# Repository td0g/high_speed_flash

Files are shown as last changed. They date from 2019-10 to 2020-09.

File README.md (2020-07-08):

# high_speed_flash
This is the data repository for my microsecond strobe designs.  They are high-speed flashes used for photographing bullets or other projectiles or processes.  The entire project is open-source.

## MK1 - The Edgerton

The original strobe was designed to be simple to assemble and as affordable as possible.  Photographers, please be aware that some soldering skills are required.

## MK2 - The E2 Series

These are called a series because multiple submodels are planned.  Currently only the E2-A is complete.

The E2 series are very similar to the MK1 Edgerton, but have been designed with commercial production in mind.  You can build one yourself, but some more complicated processes are involved.  Additionally, the total cost is slightly higher.  The advantage is that the E2 series is smaller, more robust, and easier to use.

### Planned E2 Submodels:

E2-A | E2-K | E2-V
------------ | ------------- | -------------
Standard | High-powered 1-microsecond | Videographer
**Plans & specs available** | In development | In development
Strobe only | Strobe only | **120+ Watt Constant illumination mode**
Battery only | Battery only | **Battery OR external power supply**
**0.5 - 4 microsecond strobe** | 0.5 - 1 microsecond strobe | **0.5 - 4 microsecond strobe**
Standard LED Power | **Increased LED Power** | Standard LED Power
**Well-Established Safety Margin** | LED's more likely to fail | **Well-Established Safety Margin**

## Comparison

If you are trying to decide which design to use, have a look through this comparison.  Only the E2-A submodel is compared as it is most similar to the original Edgerton.

MK1 Edgerton | MK2 E2-A
------------ | -------------
**Same Performance** | **Same Performance**
**Affordable** | About 30% more expensive
**Relatively simple to assemble** (3D printer, soldering skills, Through-Hole Components) | Slightly more difficult (Aluminum milling / drilling, better cable management required, Surface-Mount Components)
Reliable | **Reliable PLUS**
8x AA batteries | **4x AA batteries**
Battery compartment difficult to access | **Easy to use battery compartment**
Cheap display | **Attractive, intuitive display**
Larger | **Smaller**
Single strobes only | **Multi-strobe capable**

## Research & Testing
The most valuable part of this project is the research and testing.  Many LED's have been destructively tested to find their limitations.  I plan to upload all of my testing data to this repository and encourage others to share any testing performed as well.

## License

Documentation is licensed under a [Creative Commons Attribution 4.0 International License](https://creativecommons.org/licenses/by/4.0/)

Software is licensed under a [GNU GPL v3 License](https://www.gnu.org/licenses/gpl-3.0.txt)

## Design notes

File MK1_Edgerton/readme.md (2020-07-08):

# The Original Design!

Edgerton is a high-speed flash used for photographing bullets or other projectiles.  The project is open-source.  Please see https://hackaday.io/project/165622-edgerton-a-high-speed-led-flash for more information.

## Building Your Flash
Please download and follow the [Assembly Manual](https://github.com/td0g/high_speed_flash/blob/master/MK1_Edgerton/Assembly%20Manual%201.3.pdf).  This detailed manual should answer most of your questions.

The main control board can be built in several ways.  You may build it using a blank perfboard PCB (See the perfboard layout), by etching and drilling your own PCB (See the Gerber files), or by purchasing a control board from me (https://www.tindie.com/products/19592/).

The firmware has been tested and will make setup quick and easy.  Please flash it to your microcontroller using the Arduino IDE.  Before turning on your flash, please review the User's Manual.

## Files

**Assembly Manual** - The best way to build the flash

**GERBER's** - All the files you need to send to a board house if you want to have the control board built

**Firmware** - In the **edgerton** folder.  Upload using the Arduino IDE.

## License

Documentation is licensed under a [Creative Commons Attribution 4.0 International License](https://creativecommons.org/licenses/by/4.0/)

Software is licensed under a [GNU GPL v3 License](https://www.gnu.org/licenses/gpl-3.0.txt)

## ToDo

Finish this readme

EMCB0 Control Board: R6 text is under SSR, cannot see it... 220uF cap is in bad spot

Firmware: Add interrupt blocking

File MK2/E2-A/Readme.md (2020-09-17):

# The MK2!

Building on the original Edgerton design, the E2-A is a high-speed flash used for photographing bullets or other projectiles.  The project is open-source.  Please see https://td0g.ca/2020/06/29/e2-a-the-high-speed-led-strobe-mk-2/ for more information.

## Building Your Flash
Please download and follow the [Assembly Manual](https://github.com/td0g/high_speed_flash/raw/master/MK2/E2-A/E2-A%20Assembly%20Manual.pdf).  This detailed manual should answer most of your questions.  Please contact me at tyler@td0g.ca if you find any errors or inconsistencies, or simply have questions!

The **EMCB1** main control board is slightly different than the one on the original Edgerton.  I plan to manufacture a few and make them available for sale.  You can also manufacture your own using the documentation in this repository!

The **ECC0** high-voltage boost converter is my own design.  Just like the EMCB1, you may build your own or contact me to purchase one.  Note that the ECC0 may eventually be updated to be compatible with the Edgerton design, but for now the maximum input voltage is 6 Volts.

The firmware has been tested and will make setup quick and easy.  Please flash it to your microcontroller using the Arduino IDE.  Before turning on your flash, please review the User's Manual.

## Files

**Assembly Manual** - The best way to build the flash

**GERBER's** - All the files you need to send to a board house if you want to have the control board built

**BOM** - Itemized list of all materials needed to manufacture the E2-A

**Firmware** - Upload using the Arduino IDE

**STL** - 3D print files

**Mechanical Drawings** - Drawings for manufacturing the aluminum faceplate

## License

Documentation is licensed under a [Creative Commons Attribution 4.0 International License](https://creativecommons.org/licenses/by/4.0/)

Software is licensed under a [GNU GPL v3 License](https://www.gnu.org/licenses/gpl-3.0.txt)

## Roadmap

### Rev 0

COMPLETE

### Rev 1

Finish this readme

Assembly Manual - complete and upload

Back_Cover.STL - redesign external trigger jack housing

EMCB1 - Some components are placed too closely, will need to increase board width by a couple mm

Operator's Manual - update

### Rev 2

Adding third PCB to design: EIB0.  This board will be mounted near the encoder and display.  It will host the 5V and 12.8V regulator.  The 12.8V regulator will be an SX1308-based boost converter, no longer an off-the-shelf converter.  The board will be connected to the EMCB1 control board using an FFC ribbon, which will dramatically improve cable management.  Battery power will be supplied to the EMCB1 by 22-gauge wires so that the XL6005 and MIC3172 have ample current supply.

The EMCB1 board will be updated with a 'modelling lamp' function, based on the XL6005 boost converter SMPS.  Max power is ~10W, efficiency is ~60%.

The EMCB1 and ECC0 boards will be modified such that they can connect directly - no wires.  Fewer wires = fewer failure opportunities and more compact design

The film capacitors will be rotated slightly to improve spacing.

USB-C connector on case to power strobe (eg. Raspberry Pi 4 PSU).  Adding CH340 chip so that FTDI adapter isn't required for firmware updates - just use USB-C connection.  See https://github.com/sparkfun/Serial_Basic_Breakout-CH340C

INVESTIGATE: Modified version to use 18650 battery(s).  1x 18650 would run the strobe, 2x could run the XL6005 boost converter at a higher power than 4x AA batteries.

INVESTIGATE: Increasing maximum exposure time

INVESTIGATE: Replacing TC4452 gate driver with more powerful driver

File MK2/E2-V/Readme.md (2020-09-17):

# The Video Version!

An extension of the E2-A, the E2-V has all of the same functionality but includes a constant-illumination mode.  The project is open-source.  Please see https://td0g.ca/2020/06/29/e2-a-the-high-speed-led-strobe-mk-2/ for more information.

## What's The Same / Different?

Much of the design should remain the same.  The goal is to have an external power supply which can be connected in place of the battery to provide constant current to the LED's.

The gate driver needs to have an automated switch for the high-pass filter which disables the filter if the LED capacitor anode voltage is less than ~45 volts.  Otherwise the external power supply cannot provide constant current to the LED's as the transistors cannot remain on for more than 4.5 microseconds.

An offline drive would seem to be the simplest approach, but designing the driver safely presents a significant challenge.  A safer alternative would be to use a 140-watt encapsulated 36V or 48V power supply to power a buck converter.

Because the external power supply will operate with its ground common to the strobe, it requires a high-side switching buck power supply.  The LM3409HV seems to be a suitable candidate.

The buck power supply must be controlled by the strobe.  An opto-isolated interface bus would seem to be the safest way.

The external power supply must also supply a ~6-volt rail to power the strobe.  This requires yet another buck power supply.

Finally, the firmware must be heavily modified to control the power supplies safely.

## ToDo

Finish development of the LM3409HV-based LED driver

Develop 48V to 6V buck regulator

Modify firmware to support constant illumination mode

Integrate LED driver into E2 design

Ensure LED's are load balanced (https://www.onsemi.com/pub/Collateral/AND8109-D.PDF)

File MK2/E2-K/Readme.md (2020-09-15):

# The MK2 - With Extra Power!

An extension of the E2-A, the E2-K is designed for higher power and shorter strobe durations.  The project is open-source.  Please see https://td0g.ca/2020/06/29/e2-a-the-high-speed-led-strobe-mk-2/ for more information.

## What's The Same / Different?

The CREE CXA2530 remains the best bang-for-buck LED in its class.  So there's no point in using a different LED.

Adding more LED's is a possibility, but doing so would require a new mechanical design and gate driver circuit.  It's more economical to use two strobes instead of redesigning.  So the E2-K will continue to use 12x LED's.

The 120V limitation in the E2-A is well within the safe limits of the LED, given a maximum strobe duration of 4 microseconds.  It can even do it three times in a row at 1 kHz!  So, it seems possible that the LED voltage can be increased significantly - perhaps greater than 200V.  This would result in more power output.  To protect the LED's, the maximum strobe duration would be limited to 1 microsecond.  The maximum strobe rate would be set to 1 Hz - no multi-strobe bursts!

## ToDo

Develop firmware with modified limitations (1 microsecond MAX, no multi-strobes)

Source a transistor: Ids >60A, Vds >250V

Test (and possibly modify) gate driver circuit

Conduct testing to find safe limitations for E2-K

Identify causes of failure, work to prevent them

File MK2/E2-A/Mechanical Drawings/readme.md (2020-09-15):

## Files:

### Face Plate

Required for E2-A.  

Recommended material: Aluminium (Anodized if possible).  Currently looking into possibility of 3D printing this component for those who do not have access to mill.

Note: Contours in recessed slots is not strictly required, but highly recommended to prevent contact by the conductors.

### L-Bracket

Optional equipment for E2-A.  Allows mounting on 3 sides of strobe.

Recommended material: Aluminum or Steel

Note:  Contours are primarily asthetic and are not required.

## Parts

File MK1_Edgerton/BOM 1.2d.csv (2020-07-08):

Notes
 |  | Digikey is my preferred vendor (Good prices, cheapest shipping, ships from Winnipeg) but Mouser and others are good as well. Same with eBay/Alibaba/Bangood.
 |  | Most components from eBay could be purchased from Digikey, just an increase in cost (but faster shipping!)
 |  | DO NOT purchase LED’s from eBay/Alibaba. Testing has shown that LED’s from untrustworthy vendors are a lower quality.
Part# | Board Ref | Manufacturer Model | Description | Qty | Suggested Vendor | Vendor Part # | Link
1 |  | CREE CXA2530-0000-U20E3 | LED | 12 | Digikey | CXA2530-0000-000N00U20E3-ND | https://www.digikey.ca/product-detail/en/cree-inc/CXA2530-0000-000N00U20E3/CXA2530-0000-000N00U20E3-ND/3647354
2 |  | Vishay MKP1848S | 10uf Film Capacitor | 4 | Digikey | BC2783-ND | https://www.digikey.ca/product-detail/en/vishay-bc-components/MKP1848S61070JP2C/BC2783-ND/3053104
3 |  | INFINEON IPP60R190P6 | N-Channel MOSFET | 4 | Digikey | IPP60R190P6XKSA1-ND | https://www.digikey.ca/product-detail/en/infineon-technologies/IPP60R190P6XKSA1/IPP60R190P6XKSA1-ND/4248888
4 |  | 45-390V Boost Regulator | Boost Regulator | 1 | eBay |  | https://www.ebay.ca/itm/DC-DC-10-32V-to-45-390V-High-Voltage-Boost-Converter-Step-up-Booster-Module-BB/192918513095
5 |  | 5x7cm PCB Perf Board, Single-Side Tinned OR EMCB0 | PCB | 1 | eBay |  | https://www.ebay.ca/itm/10pcs-DIY-Prototype-Paper-PCB-Universal-Board-5-7-cm-5-7-cm/201414877045
6 | U3 | ATMEL ATMega328P | Microcontroller | 1 | Digikey | ATMEGA328-PU-ND | https://www.digikey.ca/product-detail/en/microchip-technology/ATMEGA328-PU/ATMEGA328-PU-ND/2271026
7 | U1 | LM7805 | Linear Regulator | 1 | eBay
8 | U4 | Microchip TC4452 | Gate Driver | 1 | Digikey | TC4452VPA-ND | https://www.digikey.ca/product-detail/en/microchip-technology/TC4452VPA/TC4452VPA-ND/1098934
9 | U2 | Vishay VO14642AT (Or similar... eBay buyers can probably use AQV252G drop-in replacement) | Solid State Relay | 1 | Digikey | VO14642AT-ND | https://www.digikey.ca/product-detail/en/vishay-semiconductor-opto-division/VO14642AT/VO14642AT-ND/4074374
10 | D1, D2 | 1N5817 | Schottky Diode | 2 | eBay |  | https://www.ebay.ca/itm/Rectifier-Diodes-10A10-1N4001-1N4007-1N5402-1N5408-1N5399-1N914-1N-series-BBC/142919748646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
11 | D3 | 1N5380 | 120V Zener Diode | 1 | Digikey
12 | C6 |  | 2.2nF 10V Ceramic Cap | 1 | eBay
13 | C1, C4, C5 | RDER71E104K0P1H03B | 100nF 10V Ceramic Capacitor, 10% | 3 | Digikey | 490-8809-ND | https://www.digikey.ca/product-detail/en/murata-electronics-north-america/RDER71E104K0P1H03B/490-8809-ND/4770964
14 | C7, C8 | FG11X7S1H106KRT06 | 10uF 25V Ceramic Capacitor | 2 | Digikey | 445-180817-1-ND | https://www.digikey.ca/product-detail/en/tdk-corporation/FG11X7S1H106KRT06/445-180817-1-ND/9560943
15 | C2 | 2.2uF 10V Ceramic Cap | Capacitor | 1 | eBay
16 | C3 | 220uF 10V Electrolytic Cap | Capacitor | 1 | eBay
17 | R1 | 47K Res | Resistor | 1 | eBay
18 | R2 | 33K Res | Resistor | 1 | eBay
19 | R3 | 10K Res | Resistor | 1 | eBay
20 | R4, R6 | 100 Res | Resistor | 2 | eBay
21 | R5, R7, R10 | 68K Res | Resistor | 3 | eBay
22 | R8 | 1.5K Res | Resistor | 1 | eBay
23 | R9 | 3.3K 1/2W Res (2x 1.6K 1/4W Res) | Resistor | 1 | eBay
24 | R11 | 2.7K Res | Resistor | 1 | eBay
25 | R12 | 39 1/4W Res | Resistor | 1 | eBay
26 |  | TM1637 Four-Segment LED Display | LED Display | 1 | eBay |  | https://www.ebay.ca/itm/4-Bits-TM1637-Digital-Tube-LED-Clock-Display-Module-For-Arduino-Due-UNO-2560-R3/310788450125
27 |  | EC11 Rotary Encoder | Mechanical Encoder | 1 | eBay |  | https://www.ebay.ca/itm/Rotary-encoder-with-switch-EC11-Audio-digital-potentiometer-20mm-handle-CA/142486141701
28 |  | AA Battery Positive Negative Contact Plate | Battery Contacts | 4 | eBay |  | https://www.ebay.ca/itm/AA-Battery-Positive-Negative-Conversion-Spring-Contact-Plate-30-Pcs-N3/122059487728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
29 |  | 1/4” Dia x 1/8” Thi Rare Earth Magnets | Magnets | 4 | eBay |  | https://www.ebay.ca/itm/20-pcs-of-1-4-dia-x-1-8-thick-Neodymium-Rare-Earth-Disc-Magnets/173904398036
30 |  | Arca-Swiss Plate | Quick-Release Mounting Plate | 1 | eBay
31 |  | M5 x 16mm Countersink-Head Screws | Fastener | 4 | eBay
32 |  | M5 Nuts | Fastener | 4 | eBay
33 |  | M4 x 20mm Socket-Head Screw | Fastener | 6 | eBay
34 |  | M3 x 8mm Socket-Head Screw | Fastener | 4 | eBay
35 |  | M2 x 12mm Socket-Head Screw | Fastener | 13 | eBay
36 |  | 22AWG Silicone Wire | Conductor | 1m | eBay |  | https://www.ebay.ca/itm/22AWG-Wire-Gauge-Silicone-Stranded-Flexible-Copper-Cable-10-Feet-Fr-RC-Black-Red/302783235558
37 |  | 3D Printing Filament | Plastic | 0.5 kg | spool3d.ca |  | https://spool3d.ca/filament/petg/1-75-mm/
38 |  | 2-ohm Metal Film Resistor, 1/4W | LED Series Resistor | 4 | Digikey | RNF14FTD2R00CT-ND | https://www.digikey.ca/product-detail/en/stackpole-electronics-inc/RNF14FTD2R00/RNF14FTD2R00CT-ND/1974961
39 |  | 200-ohm 1/4W Resistor | Resistor |  | eBay
40 |  | 28L0138-40R-10 | 5A Ferrite Bead, 135-ohm@100MHz | 4 | Digikey | 240-2513-1-ND | https://www.digikey.ca/product-detail/en/laird-signal-integrity-products/28L0138-80R-10/240-2513-1-ND/1015955
41 |  | 200uf 30V Capacitor | Capacitor | 1 | Digikey | 732-8634-1-ND | https://www.digikey.ca/product-detail/en/wurth-electronics-inc/860010473011/732-8634-1-ND/5728590
42 |  | KCD1-101 | Rectangular Power Switch | 1 | eBay |  | https://www.ebay.ca/itm/5Pcs-KCD1-101-Red-Rocker-Switch-2-Pin-KCD1-101-250V-6A-Boatlike-Switch-ST/172245048336
43 |  | 3.5mm Jack | 3.5mm Jack | 1 | eBay |  | https://www.ebay.ca/itm/10pcs-3-5mm-Headphone-Audio-Sound-Jack-Socket-Port-Connector-DC-30V-0-5A-PJ322/171907312663

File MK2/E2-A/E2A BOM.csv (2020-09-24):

 | Date | 2020-08-29
 | File | E2-A High-Speed Flash
 | Rev | 1
Notes
 |  | Digikey is my preferred vendor (Good prices, cheapest shipping, ships from Winnipeg) but Mouser and others are good as well. Same with eBay/Alibaba/Bangood.
 |  | Most components from eBay could be purchased from Digikey, just an increase in cost (but faster shipping!)
 |  | DO NOT purchase LED’s from eBay/Alibaba. Testing has shown that LED’s from untrustworthy vendors are a lower quality.
 |  | The EMCB1 and ECC0 board components will come pre-installed on the boards if purchased from td0g.
Part# | Ref | Manufacturer Model | Description | Qty | Suggested Vendor | Vendor Part # | Link
1 | LED_D1, LED_D2, LED_D3, LED_D4 | CREE CXA2530-0000-U20E3 | LED | 12 | Digikey | CXA2530-0000-000N00U20E3-ND | https://www.digikey.ca/product-detail/en/cree-inc/CXA2530-0000-000N00U20E3/CXA2530-0000-000N00U20E3-ND/3647354
2 | LED_C1 | Vishay MKP1848S | 10uf Film Capacitor | 4 | Digikey | BC2783-ND | https://www.digikey.ca/product-detail/en/vishay-bc-components/MKP1848S61070JP2C/BC2783-ND/3053104
3 | LED_Q1 | IRFB4332PBF | N-Channel MOSFET | 4 | Digikey | IRFB4332PBF-ND | https://www.digikey.ca/product-detail/en/infineon-technologies/IPP60R190P6XKSA1/IPP60R190P6XKSA1-ND/4248888
4 | LED_FB1 | 28L0138-40R-10 | 135R @ 10MHz FB | 4 | Digikey | 240-2439-1-ND | https://www.digikey.in/product-detail/en/murata-electronics/NFZ2MSD900SN10L/490-NFZ2MSD900SN10LCT-ND/11690521
5 | LED_C2 | C907U102MYVDBA7317 | 1nF 400V Cap – Snubber Circuit | 4 | Digikey | 399-9472-1-ND | https://www.digikey.ca/en/products/detail/kemet/C907U102MYVDBA7317/3645164
6 | LED_R5 | 10K 1/8W Res 0805 | Snubber Circuit Resistor | 4 | Digikey
7 | LED_R6 | RNF14FTD6R81 | Gate Resistor – 6.81R 1/4W | 4 | Digikey | RNF14FTD6R81TR-ND
8 | LED_R1, LED_R2, LED_R3, LED_R4 | NKN200JT-73-0R47 | 0R47 2W Zero-Inductance LED Series Resistor | 4 | Digikey | 0.47CECT-ND | https://www.digikey.ca/product-detail/en/stackpole-electronics-inc/RNF14FTD2R00/RNF14FTD2R00CT-ND/1974961
9 |  | S7V7F5 | Step Up/Down Regulator | 1 | BuyAPi | 700 | https://www.buyapi.ca/product/pololu-5v-step-upstep-down-voltage-regulator-s7v7f5/
10 |  | 128x64 OLED | OLED Display | 1 | Amazon.ca |  | https://www.ebay.ca/itm/4-Bits-TM1637-Digital-Tube-LED-Clock-Display-Module-For-Arduino-Due-UNO-2560-R3/310788450125
11 |  | EC11 Rotary Encoder | Mechanical Encoder | 1 | eBay |  | https://www.ebay.ca/itm/Rotary-encoder-with-switch-EC11-Audio-digital-potentiometer-20mm-handle-CA/142486141701
12 |  | AA Battery Positive Negative Contact Plate | Battery Contacts | 4 | Digikey | SNT5-1-ND | https://www.ebay.ca/itm/AA-Battery-Positive-Negative-Conversion-Spring-Contact-Plate-30-Pcs-N3/122059487728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
13 |  | AA Battery Negative Contact Plate | Battery Contacts | 1 | Digikey | 36-5223-ND
14 |  | AA Battery Positive-Negative Contact Plate | Battery Contacts | 1 |  | ?? Bought from eBay
15 |  | BUK9Y43-60E.115 | Reverse-Polarity Protection PFET | 1
16 |  | 47K 1/8W Res THT | Reverse-Polarity Protection RES | 1
17 |  | M3 x 20mm Socket-Head Screw | Fastener | 1 | eBay
18 |  | M3 x 18mm Socket-Head Screw | Fastener | 4 | eBay
19 |  | M3 x 16mm Socket-Head Screw | Fastener | 1 | eBay
20 |  | M3 x 14mm Socket-Head Screw | Fastener | 8
21 |  | M3 x 10mm Socket-Head Screw | Fastener | 6 | eBay
22 |  | M3 x 6mm Socket-Head Screw | Battery Holder Screw | 1 | eBay
23 |  | M2 x 6mm Socket-Head Screw | Fastener | 4 | eBay
24 |  | M2 x 4mm Socket-Head Screw |  | 5
25 |  | M3 Grub 4mm screw | Battery Holder Screw | 1 | eBay
26 |  | 22AWG Silicone Wire | Conductor | Roll | eBay |  | https://www.ebay.ca/itm/22AWG-Wire-Gauge-Silicone-Stranded-Flexible-Copper-Cable-10-Feet-Fr-RC-Black-Red/302783235558
27 |  | Carbon Fibre-Infused PETG or ABS Filament | Plastic | 0.5 kg | spool3d.ca |  | https://spool3d.ca/filament/petg/1-75-mm/
28 |  | KCD1-101 | Rectangular Power Switch | 1 | eBay |  | https://www.ebay.ca/itm/5Pcs-KCD1-101-Red-Rocker-Switch-2-Pin-KCD1-101-250V-6A-Boatlike-Switch-ST/172245048336
29 |  | SJ1-3523N | 3.5mm Jack – Out of stock | 1 | Digikey | CP1-3523N-ND | https://www.digikey.ca/en/products/detail/cui-devices/SJ1-3523N/738689
30 |  | EFP0 | Aluminum faceplate | 1 | td0g
31
32 |  | 1/4” - 3/8” thread adapter | Tripod Mounting Thread | 1 | Amazon.ca |  | https://www.amazon.ca/Foto-Tech-Convert-Adapter-Ballhead/dp/B00OKYWWMG
33 | SX1308 | SX1308 | Boost Converter | 1 | eBay
34 | SX1308_R1 | 510R 1/8W 0805 | Voltage Divider for boost converter | 1
35 | SX1308_R2 | 10 K1/8W 0805 | Voltage Divider for boost converter | 1
36 | EMCB1 | EMCB1 PCB | PCB – Main control board | 1 | td0g
37 | EMCB1 | DIP-18 Socket | Socket for ATMEGA328P | 1
38 | EMCB1 | DIP-8 Socket | Socket for TC4452 | 1
39 | EMCB1_BZ1 | Piezo Buzzer | Sound output | 1
40 | EMCB1_C1 | 100nF 16V Ceramic THT Cap |  | 1
41 | EMCB1_C2 | 10uF 16V Ceramic Cap 1206 |  | 1
42 | EMCB1_C3 | 220uF 16V Electrolytic THT Cap |  | 1
43 | EMCB1_C4, EMCB1_C5 | 100nF 10V Caramic Cap 0805 |  | 2
44 | EMCB1_C6 | 2.2nF 10V Ceramic THT Cap |  | 1
45 | EMCB1_C8, EMCB1_C9 | 10uF 50V Ceramic Cap 0805 |  | 2
46 | EMCB1_D1 | 1N4001 Diode |  | 1
47 | EMCB1_D2, EMCB1_D4 | 1N4148 |  | 3
48 | EMCB1_D5 | 1N5380 | 120V Zener | 1
49 | EMCB1_U1 | ATMEGA328P Microcontroller | Microcontroller | 1 |  | ATMEGA328-PU-ND
50 | EMCB1_U2 | TC4452 Gate Driver | Gate Driver | 1 |  | TC4452VPA-ND
51 | EMCB1_R1 | 33K 1/8W Res THT |  | 1
52 | EMCB1_R3, EMCB1_R16 | 10K 1/8W Res 0805 |  | 2
53 | EMCB1_R4 | 100R 1/8W Res 0805 |  | 1
54 | EMCB1_R5, EMCB1_R7, EMCB1_R10 | 68K 1/8W Res 0805 |  | 3
55 | EMCB1_R6, EMCB1_R13, EMCB1_R2 | 47K 1/8W Res 0805 |  | 3
56 | EMCB1_R8, EMCB1_R9 | 1.5K 1/8W Res 0805 |  | 2
57 | EMCB1_R11 | 2.7K 1/8W Res 0805 |  | 1
58 | EMCB1_R12 | 39R 1/8W Res 0805 |  | 1
59 | EMCB1_R14 | 100K 1/8W Res THT |  | 1
60 | EMCB1_R15 | 1R5 1/4W Res 1210 |  | 1
61 | EMCB1_R17 | 470K 0805 | Resistor | 1
62 | EMCB1_C13, EMCB1_C14 | 22pF 10V 0805 | Add to diagram | 2
63 | EMCB1_Y1 | TXC CORPORATION / 9B-16.000MAAE-B | 16MHz Crystal | 1 | Digikey | 887-2014-ND
64 | ECC0 | ECC0 PCB | PCB – Flyback converter | 1 | td0g
65 | ECC0_T1 | DA2032-ALD | Flyback Transformer | 1 | Mouser | 994-DA2032-ALD | https://www.mouser.ca/ProductDetail/Coilcraft/DA2032-ALD?qs=ZYnrCdKdyefv4mcPD%252BT0WQ==
66 | ECC0_U1 | MIC3172YM | Flyback Controller | 1 | Mouser | 998-MIC3172YM | https://www.mouser.ca/ProductDetail/Microchip-Technology-Micrel/MIC3172YM?qs=kh6iOki%2FeLFtS7jfbx4jMQ%3D%3D
67 | ECC0_D2 | 1N4148 | Schottky Diode | 2 | Mouser | 512-1N4148 | https://www.mouser.ca/ProductDetail/ON-Semiconductor-Fairchild/1N4148?qs=i4Fj9T%2FoRm8RMUhj5DeFQg%3D%3D
68 | ECC0_R2 | 10K Resistor 0805 | Resistor | 1
69 | ECC0_C5 | 1uF 250V Ceramic Capacitor 0805 | Output Cap | 1
70 | ECC0_R5 | 470K 0805 | Resistor | 1
71 | ECC0_R4 | 2.7K 0805 | Resistor | 1
72 | ECC0_RV1 | 10K Pot | Voltage Adjust Pot | 1
73 | ECC0_C4 | 1uF 16V Ceramic Capacitor 0805 | Capacitor | 1
74 | ECC0_C1 | 10uF 16V Ceramic Capacitor 0805 | Capacitor | 2
75 | ECC0_R1 | 1K 1/8W Resistor 0805 |  | 1
76 | ECC0_R3 | 470K 1/8W Resistor THT |  | 1

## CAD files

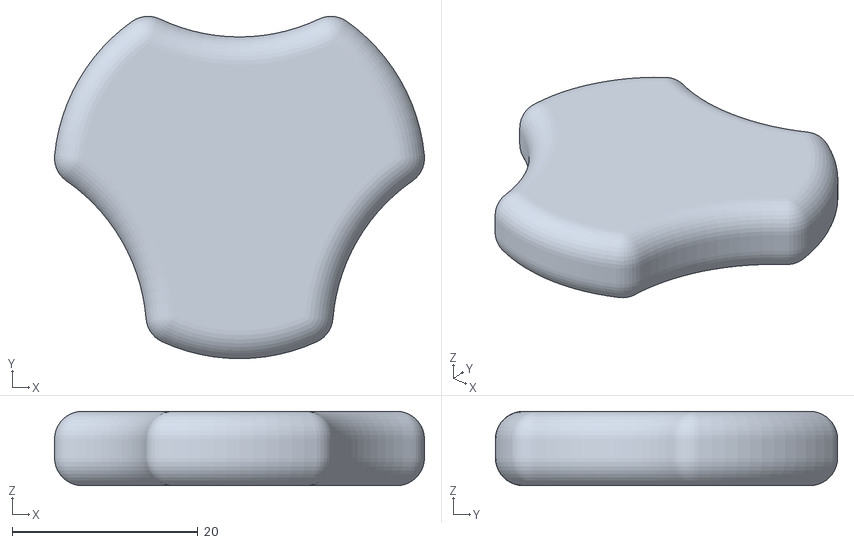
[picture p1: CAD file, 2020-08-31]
MK1_Edgerton/STL/Dial.STL
39.8 x 36.9 x 8.00

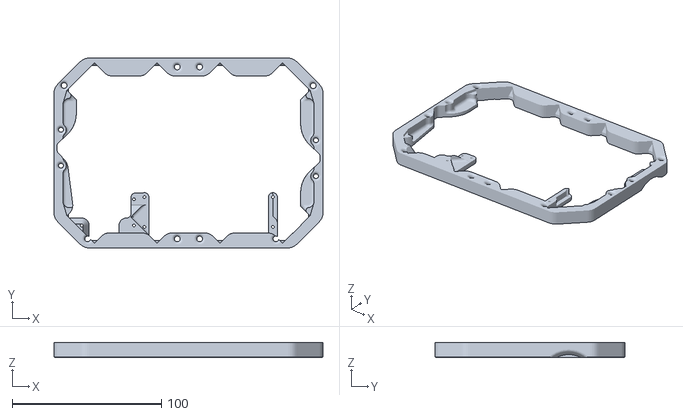
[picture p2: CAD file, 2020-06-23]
MK2/E2-A/STL/Intermediate_Section.stl
180.0 x 127.0 x 10.0

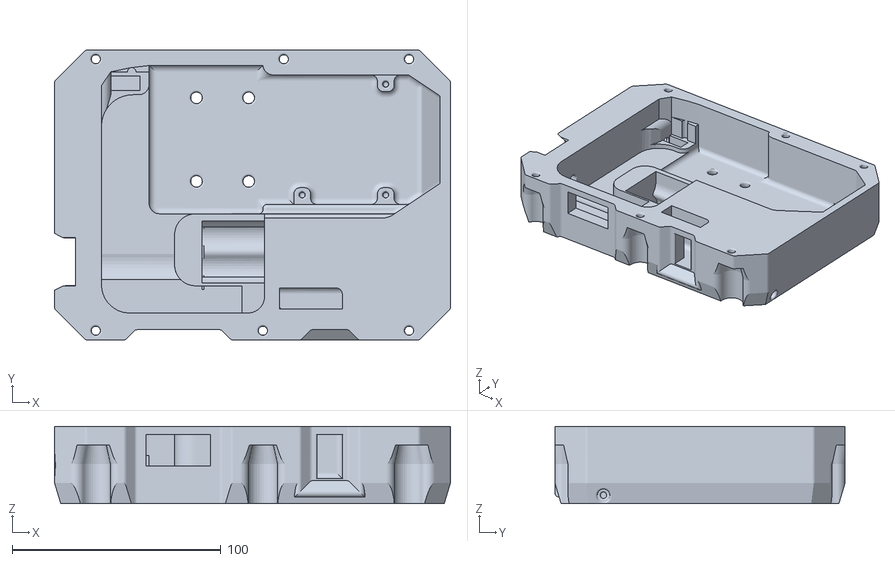
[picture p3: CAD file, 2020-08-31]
MK1_Edgerton/STL/Mid Body.STL
189.6 x 139.0 x 37.0

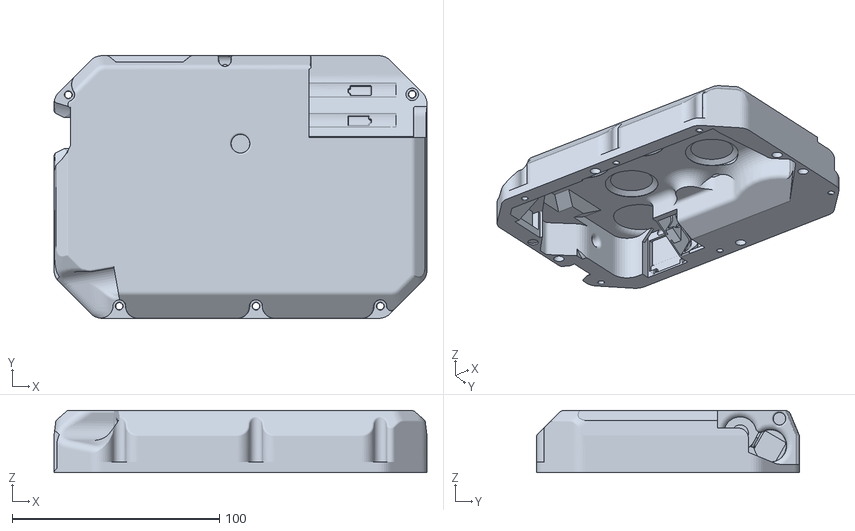
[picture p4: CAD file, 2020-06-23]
MK2/E2-A/STL/Back_Cover.stl
180.0 x 126.8 x 30.0

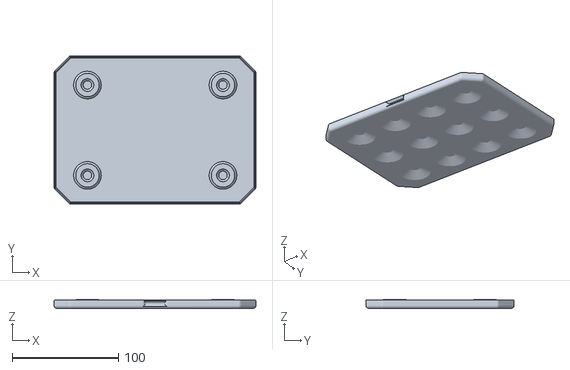
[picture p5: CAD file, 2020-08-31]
MK1_Edgerton/STL/LED Cover.STL
190.0 x 139.5 x 8.50

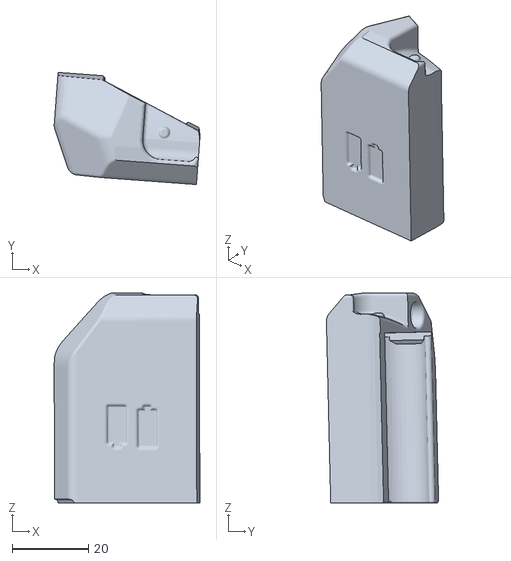
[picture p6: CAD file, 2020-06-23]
MK2/E2-A/STL/Battery_Holder.stl
38.1 x 29.4 x 55.0

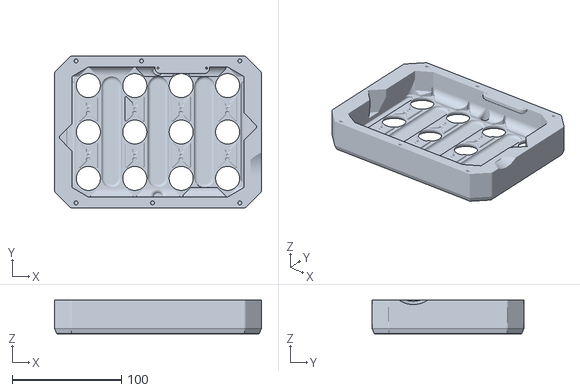
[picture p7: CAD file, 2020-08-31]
MK1_Edgerton/STL/Front.STL
189.6 x 139.1 x 30.8

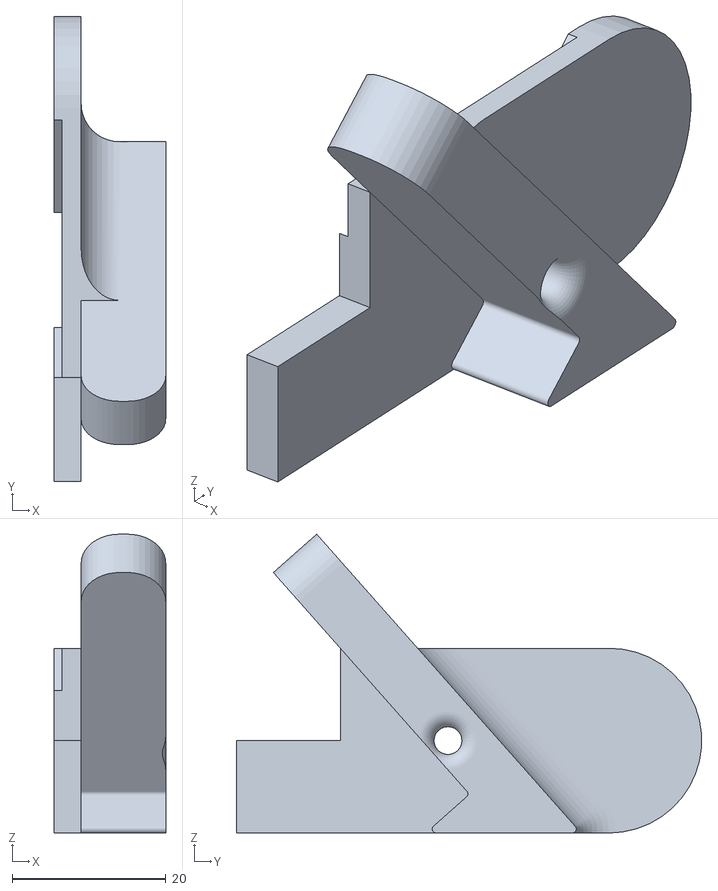
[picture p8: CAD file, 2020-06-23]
MK2/E2-A/STL/TEMPLATE_LED_Clamp.stl
14.5 x 60.5 x 38.8

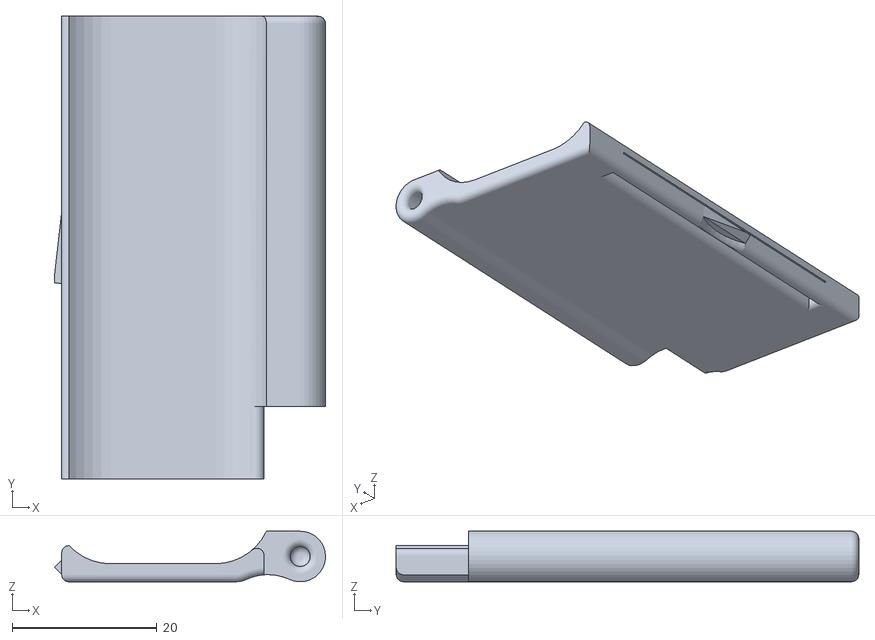
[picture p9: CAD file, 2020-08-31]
MK1_Edgerton/STL/Battery Door.STL
37.5 x 64.0 x 7.00

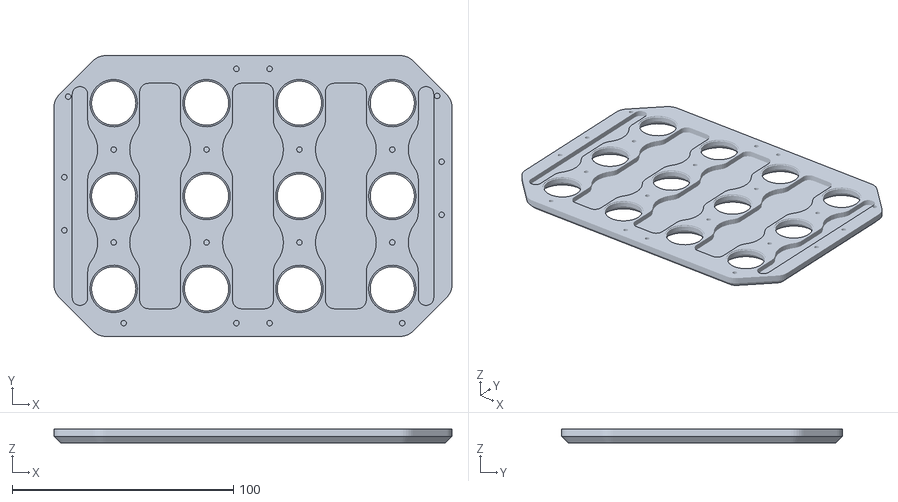
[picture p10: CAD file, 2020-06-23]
MK2/E2-A/STL/Faceplate.stl
180.0 x 127.0 x 6.30

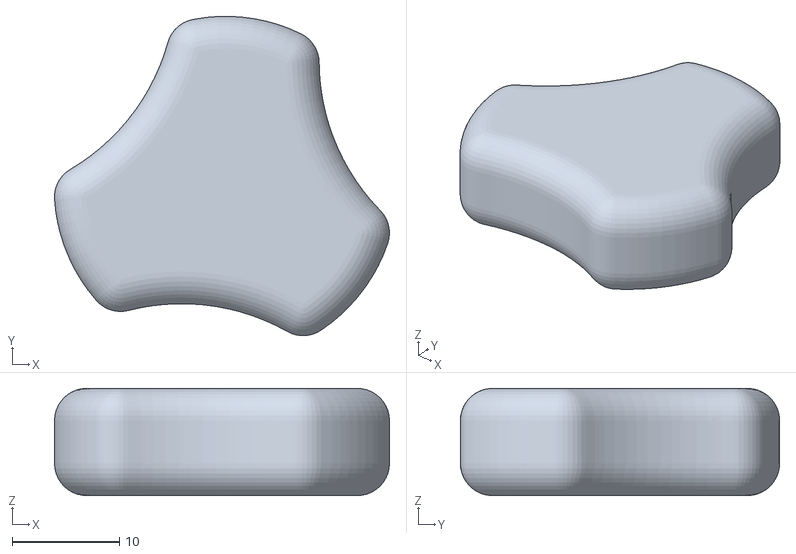
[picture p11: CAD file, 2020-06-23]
MK2/E2-A/STL/Dial.stl
31.3 x 29.8 x 10.0

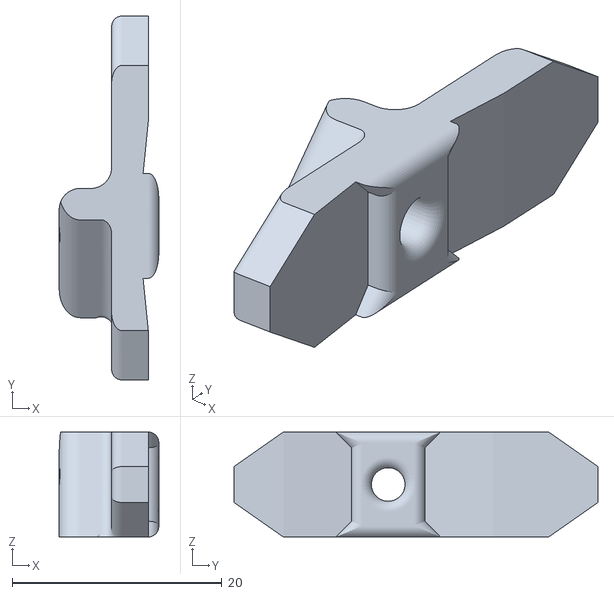
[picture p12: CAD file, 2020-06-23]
MK2/E2-A/STL/LED Clamp.stl
9.50 x 34.7 x 10.00

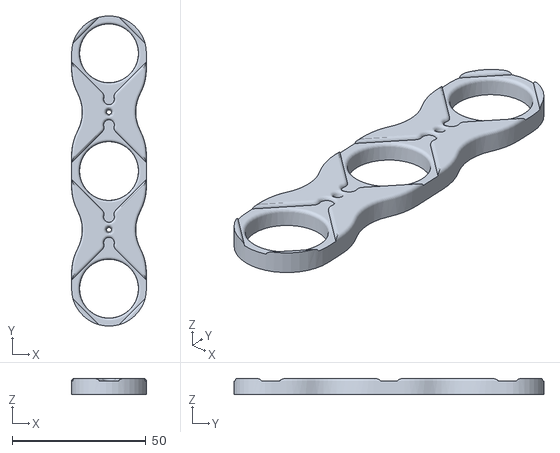
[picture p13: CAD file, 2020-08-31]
MK1_Edgerton/STL/Template.STL
28.0 x 115.9 x 6.00

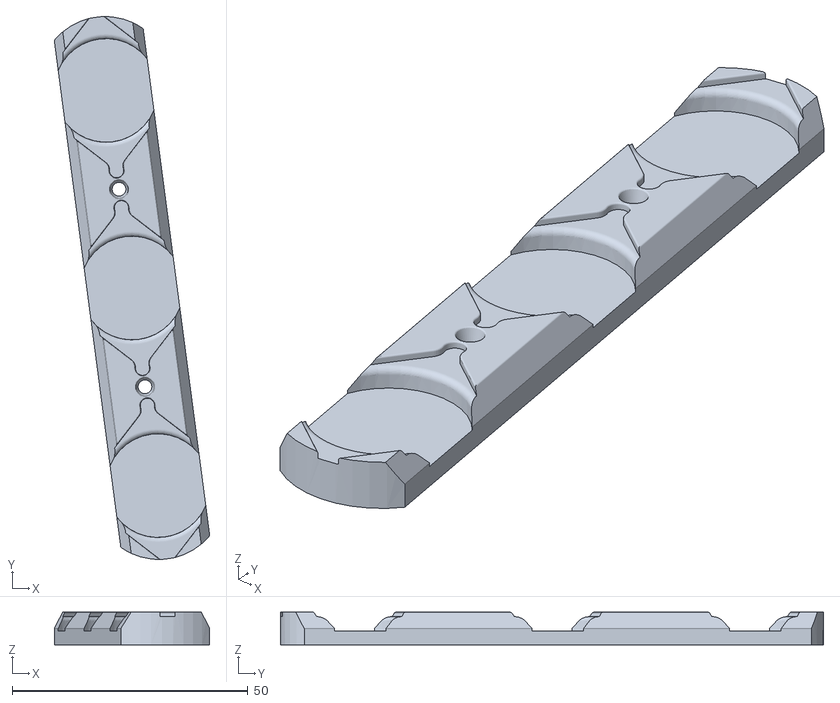
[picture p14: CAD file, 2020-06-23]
MK2/E2-A/STL/TEMPLATE_Base.stl
33.0 x 115.3 x 7.00

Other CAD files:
MK1_Edgerton/STL/Back.stl
MK1_Edgerton/STL/Fixture.STL
MK1_Edgerton/STL/LED Clamp.STL

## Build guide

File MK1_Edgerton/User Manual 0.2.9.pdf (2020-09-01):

Edgerton User’s Manual 0.2.9

# Edgerton User’s Manual

## Description

This is a user’s manual manual for Edgerton, the High-Speed LED Flash. The User Interface (UI)
For a complete overview of Edgerton, please visit https://td0g.ca/2019/05/14/edgerton-a-high-speedled-flash-diy/. (https://td0g.ca/2019/05/14/edgerton-a-high-speed-led-flash-diy/) For the data repository, please visit https://github.com/td0g/high_speed_flash.

## Batteries

For Edgerton Classic, eight AA batteries are required (8.8 – 12 V). Both alkaline and rechargeable batteries are suitable, although rechargable batteries will require a fairly full charge in order to provide the 8.8V required by the high-voltage converter.

## Calibration

Before using Edgerton, a calibration must be performed. The calibration procedure is described in the assembly manual. DO NOT use Edgerton prior to calibration.

## Usage

Settings
When Edgerton is turned on, the settings are displayed. There are two settings:
- Flash duration (0.5us, 1us, 2us, 4us)
- Trigger delay (no units will be displayed). The colon acts as a decimal point, making the shortest delay 0.05 milliseconds (50 microseconds).
The settings can be adjusted by turning the encoder. To switch between settings, click the encoder once.

Triggering
The trigger port accepts a 3.5mm jack. The trigger behaves similar to a typical hotshoe-style camera flash: the 3.5mm plug base is grounded and the tip is held high by a pullup resistor. When the state of the trigger changes, the unit will sound a high- or low- frequency chirp to indicate the change. Once in standby mode, the unit will trigger on a change in trigger state (low to high or high to low).
If a delay setting of 0 is selected, the unit will fire within microseconds of a trigger. If a delay greater than 0 is selected, the trigger will start timer and delay until the desired number of milliseconds have elapsed before strobing.

Charging & Strobing
Once the appropriate settings are selected, the flash can be charged by holding the encoder until a chime is heard. The capacitor voltage will be displayed during charging, which typically takes a couple seconds. When charging is complete, the unit will sound a second chime and the display will turn off. While the capacitors are charged, the high-voltage converter will be active. This consumes a significant amount of energy from the batteries. To turn the converter off and return to the settings menu, simply press the encoder.

Serial Communication
If the flash controller is connected to a PC using an FTDI adapter, the following commands can be issued through a serial console (eg. Arduino, Termite). Any invalid commands will be responded with a brief ‘help’ description.
SERIAL COMMAND | DESCRIPTION | DETAILS
p | Print flash history | Prints the most recent flash records in chronological order. Data includes the flash duration, voltage, and calculated current.
e | Erase flash history | Clears all entries in the flash history memory. Does not clear the total flash count.

Troubleshooting
If the flash displays an error code (such as ‘E01’), please refer to the chart below.
ERROR CODE | DESCRIPTION | SOLUTION
E01 | Low Input Voltage | Replace batteries
E02 | Capacitors Not Charging | Replace batteries, check internal components

Changelog
2020-04-21 VTG Initial Commit
2020-05-06 VTG Added ‘Serial Communication’ section 2020-09-01 VTG Firmware updted to 0.2.9

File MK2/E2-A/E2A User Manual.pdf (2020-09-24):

E2A User Manual.odt

# E2-A High-Speed Strobe

# User Manual

Tyler Gerritsen

## Table of Contents

## Description

## Working Principle

The E2-A is an LED-based photographic strobe which can produce strobes lasting from 500 nanoseconds to 4 microseconds. In order to create sufficient exposure (total light) in such a short amount of time, 12 high-powered CREE COB LED’s are used. The LED’s were selected for maximum brightness given their cost. The LED’s are driven at currents many times higher than their rated current, resulting in significantly higher light output than rated by the manufacturer.

## Advantages

Typical xenon flashtube-based strobes (‘Speedlight’ flashes) are designed for typical photographic applications such as sports, portrait, or macro photography. When attempting to image high-speed subjects (such as a bullet), the duration of the light is far too long to ‘freeze’ the subject. The E2-A is a ‘high-speed’ strobe designed to produce extremely short bursts of light which results in much sharper images with less motion blur.
In addition to the prolonged flash duration, the ramp-up and ramp-down characteristics of the flashtube are not ideal. The image is exposed in a non-uniform manner, resulting in difficulty identifying the leading and trailing edges of the subject. The E2-A’s LED’s ramp up and down rapidly (about 200 nanoseconds) which prevents the faded edges.
Finally, the E2-A’s response time to a trigger input is orders of magnitude faster than a standard photographic flash. This simplifies the trigger timing for imaging high-speed objects at a particular position.

## Disadvantages

Because the exposure duration is incredibly short, the resulting image exposure is less than that produced by a typical flashtube strobe (even at its lowest power). Compensation for the reduced exposure can include adjustment of camera settings (aperture and ISO), changing the lighting setup (moving the flash closer to the subject), and using a reflector to focus the flash’s output.
The LED current has been carefully selected by destructively testing numerous LED’s. Multiple factors can result in LED failure including maximum current draw, strobe duration, and turn-on and turn-off current rates and profiles. While the E2-A has a design factor which provides a significant margin of safety, the use of LED’s so far above their rated current can always pose the danger of damage to the LED’s. Early failures are identified during the quality control protocol which involves several thousand strobes. If damage has not yet occurred, the LED’s are expected to last at least one hundred-thousand strobes.

## Caution

The strobe contains capacitors which are charged to a dangerous voltage.
- Do not disassemble the strobe
- If disassembly is absolutely necessary, remove the batteries prior to doing so
- Keep the strobe dry

The strobe is equipped with a basic input protection circuit on the trigger circuit.
- It is recommended not to apply a voltage to the trigger input. A switch or transistor can be used to transmit a trigger signal. When using an Arduino or other development board to trigger the flash, simply toggle the GPIO pin from tri-state (INPUT) to sinking (OUTPUT LOW) to transmit the trigger signal.
- If applying a voltage is necessary, then do not apply a reverse voltage to the trigger input. The 3.5mm connector tip MUST be postivie relative to the base. Do not apply more than 5V to the trigger.

## User Interface

The strobe is equipped with a simple user interface consisting of a display, encoder (dial), and audio element.
The display is always on unless the unit is turned off or is in a FULLY ARMED state, at which point it turns off to prevent unintended image exposure. After a strobe, the display will stay on for one second or until the trigger signal is released, whichever is longer.
The encoder can be turned to adjust a setting. It can also be depressed to change menu screens. A short-press of the encoder will cycle to the next menu screen, and a long-hold will cycle between the READY TO ARM and FULLY ARMED states (described below).
The battery voltage is displayed on the bottom of the screen. The LED anode voltage is also displayed when the strobe is charged. A flashing battery voltage indicates that the battery voltage is too low for operation.

## Strobe Settings

## Settings Screens

The E2-A has five menu screens. Following is a summary of the menu screens, the allowable values, and how to navigate between screens.

Menu Screen | Values | Short Button Press | Long Button Press | Trigger Input
Strobe Duration | 0.5, 1.0, 2.0, 4.0 us | Multi-Strobe Screen | READY TO ARM | -
Multi-Strobe | 1x - 6x | Strobe Rate Screen
Strobe Rate | 250 us – 2,000 us | Initial Delay Screen
Initial Delay | 0 – 9,999 ms | Strobe Duration
| - | Screen READY TO ARM | FULLY ARMED | FULLY ARMED

Table 1: Menu Screens
Following are summaries of the settings and how operation is affected.
- Strobe Duration – The total illumination time of each individual strobe. Note that a shorter strobe duration will result in less motion blur and lower exposure. Each strobe duration setting produces one stop more or less light than the next (0.5 us produces one stop less light than 1.0 us, etc.)
- Multi-Strobe – The number of consecutive strobes per trigger. Default is a single strobe. If a single strobe is selected, then the Strobe Rate screen is not available.
- Strobe Rate – The time between the start of one strobe to the start of the next strobe. IE., if a 4.0 us strobe duration is set with 250 us between strobes, the second strobe will start 246 us after the first ends.
- Initial Delay – The time delay (in milliseconds) between the trigger signal and the first strobe.

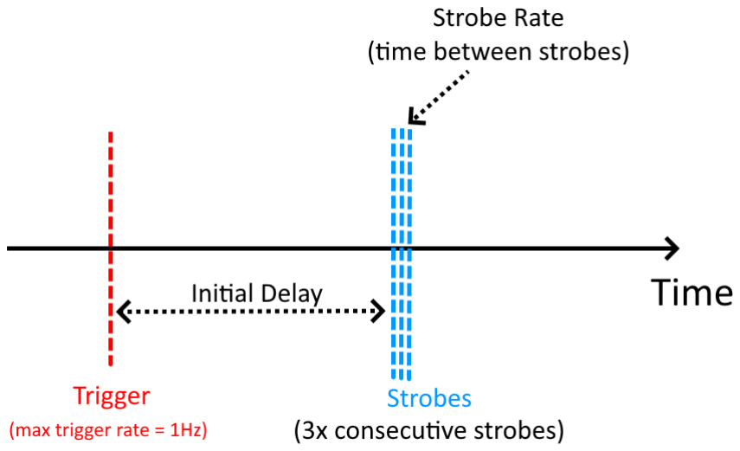
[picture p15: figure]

## Multi-Strobe Limitations

The strobe was designed to overdrive the LED’s significantly in order to achieve the exposure level in an extremely short period of time. Single strobes do not damage the LED as the duration of the strobe is too short to generate damaging levels of heat. Multi-strobes can also be performed without damaging the LED, but limitations have been installed to prevent excessive strobing which can eventually lead to LED damage.
The following three tables describe the multi-strobe limitations. All three tables describe the same limitations.

Figure 1: Multi-Strobe

Strobe Duration | Strobe Rate (delay between strobes)
250 us | 500 us | 750 us | 1,000 us | 1,250 us | 1,500 us | 1,750 us | 2,000 us
0.5 us | 6x
1.0 us | 4x | 6x
2.0 us | 2x | 4x
4.0 us | 1x | 2x
Table 2: Max Consecutive Strobes
# Consecutive Strobes | Strobe Rate (delay between strobes)

250 us | 500 us | 750 us | 1,000 us | 1,250 us | 1,500 us | 1,750 us | 2,000 us
2x | 2.0 us | 4.0 us
3x | 1.0 us | 2.0 us
4x
5x | 0.5 us | 1.0 us
6x
Table 3: Max Strobe Duration
Strobe Duration | # Consecutive Strobes
2x | 3x | 4x | 5x | 6x
0.5 us | 250 us
1.0 us | 250 us | 1,000 us
2.0 us | 1,000 us | - | -
4.0 us | 1,000 us | - | - | - | -
Table 4: Max Strobe Rate (minimum delay between strobes)

## Arming & Triggering

## Arming

The strobe will not fire unless it is in the FULLY ARMED state. In this state, the display is turned off and the strobe will wait until the strobe has fired or the unit has been turned off.
In order to enter the FULLY ARMED state, the strobe’s button must be held until the display shows READY TO ARM. The strobe is not yet armed. A second long-hold of the button or a long-hold of the trigger signal will set the strobe in the FULLY ARMED state. A short button press in the READY TO ARM screen will return to the other settings screens.
When the unit is in the READY TO ARM or FULLY ARMED states, the capacitor charger turns on and rapidly charges the capacitor anodes.

## Triggering

Once the strobe has entered the FULLY ARMED state, it is ready to flash. The only way to exit the FULLY ARMED state without firing the strobe is to turn the unit off. If the ArmLock setting is enabled, the strobe will remain in a FULLY ARMED state until it is turned off. This is useful if the strobe is connected to a function generator or intervalometer for continuous strobing. If the ArmLock setting is disabled, the unit will return to the READY TO ARM state.
The trigger port accepts a 3.5mm connector. The trigger behaves similar to a typical hotshoe-style camera flash: the 3.5mm plug base is grounded and the tip is held high by a an internal pullup resistor.
- When the state of the trigger changes while the settings menu is displayed, the unit will sound a high- or low- frequency chirp to indicate the change.
- When the strobe is in the READY TO ARM state, holding the trigger will cause the unit to enter the FULLY ARMED state.
- Once in the FULLY ARMED state, the unit will trigger on a change in trigger state (low to high or high to low).
Note that the maximum triggering rate is approximately 1 trigger per second. This limitation is designed to prevent damage to the LED’s by frequent strobing.
Also, note that the response time in Active-Low triggering is shorter than Active-High triggering. When strobe timing is critical, use a normally-open switch or change from Tri-State (INPUT) to Sinking (OUTPUT LOW) for fastest response time.

## 3.5mm Connector Wiring

Below is a simple wiring diagram which shows two possible solutions for triggering. Note that the sleeve is unused and is not internally connected (currently reserved for potential future use).
To use a simple pushbutton switch or optoisolator, the red wires indicate how the connection can be made. When using an optoisolator or any other semiconductor switch, note that the barrel has an internal pullup resistor and the tip is grounded.
When using a function generator, the blue diagram indicates how the connection can be made.

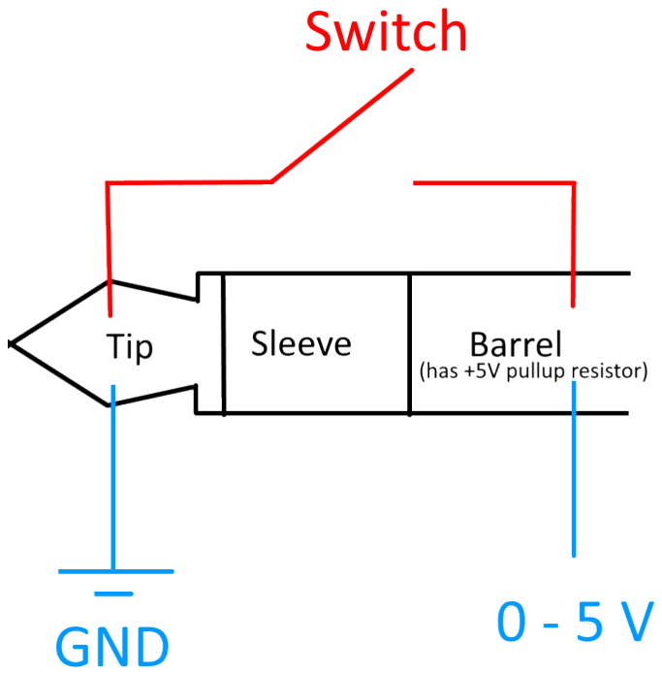
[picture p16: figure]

Figure 2: 3.5mm Jack Connections: Passive (red) and Active (Blue) triggering

## System Settings and Status

## Settings Menu

The strobe has a System Settings Menu. In order to access it, the encoder button must be held for about five seconds while the strobe is turned on. After five seconds of holding the button, the strobe will neter the System Settings Menu.
Once in the system settings menu, turning the encoder will adjust the setting and pressing the encoder will cycle to the next setting adjustment. The settings will be saved by cycling through all settings and returning to the strobe menu screen.
The following settings can be adjusted:
- Encoder Reversal: reverses direction of encoder rotation
- Display Flip: rotates the display 180 degrees
- Sound: turns the sound on and off
- ArmLock (new to firmware version 1.2): the strobe will remain in a fully armed state after each strobe – useful for connection to a function generator or intervalometer
- CalBattery2V, CalBattery6V, CalAnode: calibration factors for the battery and capacitor voltages. These calibration factors are usually set during the initial setup and are never adjusted afterward.
The strobe can also be reset to original factory settings. Simply press the button several times until the System Status Menu is reached, then hold the button for about one second.

## Status Menu

The second page of the System Settings Menu is a System Status Menu. The Serial Number and Firmware Version are displayed in the System Status Menu. Each strobe duration displays the actual number of strobes fired at that duration, so a 4x 1-microsecond strobe trigger will increment the 1-microsecond counter by 4. The TOTAL count only increments by one for each trigger, regardless of the number of strobes. For instance, the 4x 1-microsecond strobe trigger will increment the TOTAL count by 1.

## Specifications

Batteries: | 4x AA (Alkaline OR Rechargable)
Input Voltage: | 2.5V – 6.0V
Illumination Duration: | 0.5 – 4.0 microseconds
Illumination Rise/Fall: | 200 nanoseconds
Trigger Delay: | 1 microsecond (active-low) / 5 microsecond (active-high)
Max External Trigger Rate: 1 Hz
External Trigger Voltage: | 0V – 5V
Size: | Appr. 180mm x 125mm x 45mm (W x H x D)
Mass: | Appr. 650 grams
Expected Life: | >100,000 strobes

## License

This manual and all other documentation of the E2-A are licensed under the Creative Commons Attribution 4.0 International License. (https://creativecommons.org/licenses/by/4.0/)
The firmware for the E2-A strobe is licensed under a GNU GPL v3 License. (https://www.gnu.org/licenses/gpl-3.0.txt)

## Changelog

2020-06-12 VTG Initial Commit, Firmware v1.0 2020-09-24 VTG Reviewed manual, updated for FW v1.2

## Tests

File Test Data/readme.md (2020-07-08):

# Research and Development Testing Data

The high-speed flash project relies heavily on testing to find the limitations of the LED's.  Without understanding the limits, a high-speed flash will either (1) underperform, resulting in higher costs and inferior performance, or (2) fail prematurely.

## Overview of the Test Data

I have a significant amount of testing data available in my personal notes.  The testing data is slowly being uploaded to this repository.

Testing data includes measurements of the LED performance under various conditions, conditions under which the LED's will fail, and other tests related to the strobe's infrastructure (control board, power supply architecture, etc.)

## A Brief History

During development of the original Edgerton, I had access to an oscilloscope and camera.  It came as a surprise that my Sekonic L-358 was unable to measure the light output from the flash.  Many days were spent strobing LED's at a low frequency (1 - 2 hz) at various drive voltages to establish the limitations.

Since then, I've come to acquire my own oscilloscope, an [active light probe](https://www.instructables.com/id/Light-Probe-MK-I/) (Thank you NQTRONIX for your donation!!!), an integrating sphere, and various other testing equipment.  With this new equipment, I've been able to focus on the actual light output from the LED's instead of simply the voltage they could handle.

Unfortunately, my earlier tests were not as well documented as I would have liked.  Every LED failure has been documented in my notes, but I tended to 'thrash' in testing, resulting in poor documentation leading up to the failures.  The documentation of the tests have improved recently.

## Future Goals

I plan to continue destructive testing of LED's in order to find ways to improve the performance and robustness of the flash.

I am also working to find a method of examining the failed LED's so that the mode of failure can be better understood.

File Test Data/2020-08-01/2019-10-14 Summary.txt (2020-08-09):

Goal:
	Measure the T0.1 and T0.5 durations of a selection of speedlight strobes

Equipment: 
	NQTRONIX Active Probe
	Siglent SDS1200-X oscilloscope
	55-cm integrating sphere
	Nikon SB-910
	Nikon SB-800
	Canon 430EX-II
	Yongnuo YN-460 II
	
Setup:
	3x strobes per power setting per speedlight
	Increase power until active probe signal begins clipping, then stop immediately
    
Tests:
2020-08-01:
    Nikon SB-800 LO 1   (REMOVED - checked data later and found problems)
    Nikon SB-800 LO 2   (REMOVED - checked data later and found problems)
    Nikon SB-800 LO 3   (REMOVED - checked data later and found problems)
    Nikon SB-800 1/128 1   (REMOVED - checked data later and found problems)
    Nikon SB-800 1/128 2   (REMOVED - checked data later and found problems)
    Nikon SB-800 1/128 3   (REMOVED - checked data later and found problems)
    Nikon SB-800 1/64 1   (REMOVED - checked data later and found problems)
    Nikon SB-800 1/64 2   (REMOVED - checked data later and found problems)
    Nikon SB-800 1/64 3   (REMOVED - checked data later and found problems)
    Nikon SB-800 1/64 4   (REMOVED - checked data later and found problems)
    Nikon SB-800 1/32 1   (REMOVED - checked data later and found problems)
    Yongnuo YN-460 II 1/128 1
    Yongnuo YN-460 II 1/128 2
    Yongnuo YN-460 II 1/128 3
    Yongnuo YN-460 II 1/64 1
    Yongnuo YN-460 II 1/64 2
    Yongnuo YN-460 II 1/64 3
    Yongnuo YN-460 II 1/32 1
    Canon 430EX-II LO 1
    Canon 430EX-II LO 2
    Canon 430EX-II LO 3
    Canon 430EX-II 1/128 1
    Canon 430EX-II 1/128 2
    Canon 430EX-II 1/128 3
    Canon 430EX-II 1/64 1
    Canon 430EX-II 1/64 2
    Canon 430EX-II 1/64 3
    Canon 430EX-II 1/64 4
    Canon 430EX-II 1/64 5
    Canon 430EX-II 1/64 6
    Canon 430EX-II 1/32 1
    Canon 430EX-II 1/32 2
    Canon 430EX-II 1/32 3
    Canon 430EX-II 1/16 1
    Nikon SB-910 LO 1
    Nikon SB-910 LO 2
    Nikon SB-910 LO 3
    Nikon SB-910 1/128 1
    Nikon SB-910 1/128 2
    Nikon SB-910 1/128 3
    Nikon SB-910 1/64 1
    Nikon SB-910 1/64 2
    Nikon SB-910 1/64 3
    Nikon SB-910 1/32 1
    Nikon SB-910 1/32 2
    Nikon SB-910 1/32 3
    Nikon SB-910 1/16 1
2020-08-06:
    Nikon SB-800 1/128 1 (No Cactus)
    Nikon SB-800 LO (Strange Setup) 1
    Nikon SB-800 LO (Strange Setup) 2
    Nikon SB-800 LO (Strange Setup) 3
    Nikon SB-800 LO 1
    Nikon SB-800 LO 2
    Nikon SB-800 LO 3
    Nikon SB-800 1/128 1
    Nikon SB-800 1/128 2
    Nikon SB-800 1/128 3
    Nikon SB-800 1/64 1
    Nikon SB-800 1/64 2
    Nikon SB-800 1/64 3
    Nikon SB-800 1/32 1
    Nikon SB-800 1/32 2
    Nikon SB-800 1/32 3
    Nikon SB-800 1/16 1
    Nikon SB-800 1/128 1 (No Cactus)
    Nikon SB-800 1/64 1 (No Cactus)
    Nikon SB-800 1/32 1 (No Cactus)
    Nikon SB-800 1/16 1 (No Cactus)
2020-08-08 (NO CACTUS):
    Nikon SB-800 1/128 1
    Nikon SB-800 1/128 2
    Nikon SB-800 1/128 3
    Nikon SB-800 1/64 1
    Nikon SB-800 1/64 2
    Nikon SB-800 1/64 3
    Nikon SB-800 1/64 4
    Nikon SB-800 1/32 1
    Nikon SB-800 1/32 2
    Nikon SB-800 1/32 3
    Nikon SB-800 1/16 1
    Nikon SB-800 1/128 105mm 1 (SEPARATED - Testing sensitivity to beam angle)
    Nikon SB-800 1/128 105mm 2 (SEPARATED - Testing sensitivity to beam angle)
    Nikon SB-800 1/128 105mm 3 (SEPARATED - Testing sensitivity to beam angle)
    Nikon SB-800 1/64 105mm 1 (SEPARATED - Testing sensitivity to beam angle)
    Nikon SB-800 1/64 105mm 2 (SEPARATED - Testing sensitivity to beam angle)
    Nikon SB-800 1/64 105mm 3 (SEPARATED - Testing sensitivity to beam angle)
    Nikon SB-800 1/64 105mm 4 (SEPARATED - Testing sensitivity to beam angle)
    Nikon SB-800 1/32 105mm 1 (SEPARATED - Testing sensitivity to beam angle)
    Nikon SB-800 1/32 105mm 2 (SEPARATED - Testing sensitivity to beam angle)
    Nikon SB-800 1/32 105mm 3 (SEPARATED - Testing sensitivity to beam angle)
    Nikon SB-800 1/16 105mm 1 (SEPARATED - Testing sensitivity to beam angle)
    Yongnuo YN-460 II 1/128 1
    Yongnuo YN-460 II 1/128 2
    Yongnuo YN-460 II 1/128 3
    Yongnuo YN-460 II 1/64 1
    Yongnuo YN-460 II 1/64 2
    Yongnuo YN-460 II 1/64 3
    Yongnuo YN-460 II 1/32 1
    Canon 430EX-II 1/64 1
    Canon 430EX-II 1/64 2
    Canon 430EX-II 1/64 3
    Canon 430EX-II 1/32 1
    Canon 430EX-II 1/32 2
    Canon 430EX-II 1/32 3
    Canon 430EX-II 1/16 1
    Canon 430EX-II 1/16 2
    Canon 430EX-II 1/16 3
    Canon 430EX-II 1/8 1
    Nikon SB-910 1/128 1
    Nikon SB-910 1/128 2
    Nikon SB-910 1/128 3
    Nikon SB-910 1/64 1
    Nikon SB-910 1/64 2
    Nikon SB-910 1/64 3
    Nikon SB-910 1/32 1
    Nikon SB-910 1/32 2
    Nikon SB-910 1/32 3
    Yongnuo YN-460 II #2 1/128 1
    Yongnuo YN-460 II #2 1/128 2
    Yongnuo YN-460 II #2 1/128 3
    Yongnuo YN-460 II #2 1/64 1
    Yongnuo YN-460 II #2 1/64 2
    Yongnuo YN-460 II #2 1/64 3
    Yongnuo YN-460 II #2 1/32 1

Results:
	Some flashes are faster than others
    A small benefit is gained by using a Cactus V6
    Nothing replaces a microsecond strobe!

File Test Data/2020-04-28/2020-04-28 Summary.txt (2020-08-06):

Goal:
	Measure typical speedlight flash durations

Equipment: 
	Siglent SDS1200X-E Oscilloscope
	NQTRONIX Active Light Probe
	Integrating Sphere
	Canon 430EX-II
	Yongnuo YN560-II
	Nikon SB-910
	
Setup:
	Install 10-stop AND 6-stop ND filter in integrating sphere sensor port (active light probe clipping without both filters.  I need to get a 2-stop filter to fill in the gap.)
	Mount flash unit on top of integrating sphere
	
Procedure:
	3x pulses per full stop power
	eg. 3x @ 1/4, 3x @ 1/2, etc.
	Stopped @ 1/1 power
	Beginning at lowest power
		Nikon: 1/128, 1/64, 1/32, 1/16, 1/8, 1/4, 1/2, 1/1
		Canon: 1/64, 1/32, 1/16, 1/8, 1/4, 1/2, 1/1
		Yongnuo: 1/128, 1/64, 1/32, 1/16, 1/8, 1/4, 1/2, 1/1
	Coverage set to widest
		Nikon: 28mm
		Canon: 24mm
		Yongnuo: 28mm
	One extra test set performed with Nikon's diffuser on
	
Results:
	Nikon and Yongnuo have shorter durations than the Canon @ minimum power.  Note that Nikon & Yongnuo are 1/128 and Canon is 1/64 min power.
	Duration does not increase linearly with power.
	Going from minimum power --> minimum power + 1 is less than 2x duration.  Going from 1/2 to 1/1 power is several times the duration
	Interestingly, all three flash units seem to compensate for low power output with additional duration at higher power.  Just because the flash's ready light is illuminated doesn't mean it is FULLY charged.
	
Comments:
	Results are satisfactory
	Noise in the trace is mostly due to the very low signal input (a 10-stop ND filter wasn't quite strong enough to prevent clipping, the 16-stop total filter was way too much).
	Also, noise seems to be different depending on the mode that the probe's TPS61040 boost converter is operating in (PWM vs PFM)

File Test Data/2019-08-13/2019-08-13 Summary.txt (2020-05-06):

Goal:
	Measure current-voltage relationship of CREE CXA2530 LED
	This will help with design of MK2 flash (constant illumination mode)

Equipment: 
	1x Cree CXA2530 LED
	Lab power supply
	2x multimeters
	
Setup:
	Lab power supply connected directly to LED (with one multimeter in series to measure current)
	Second multimeter measuring voltage
	
Results:
	29.9V = 0.002A = 0.06W
	30.5V = 0.012A = 0.37W
	31.0V = 0.030A = 0.93W
	31.5V = 0.066A = 2.08W
	32.0V = 0.112A = 3.58W
	32.5V = 0.171A = 5.56W
	33.0V = 0.245A = 8.09W
	33.5V = 0.338A = 11.32W
	34.0V = 0.439A = 14.93W
	34.5V = 0.558A = 19.25W
	34.9V = 0.662A = 23.10W
	LED is warm but not hot

Comments:
	The datasheet indicats a maximum forward current of 1.6A.  This requires good thermal management.
	The results seem to fit the datasheet's 105 degree C curve best, even though the LED remained fairly cool.
	Given the assembly will be equipepd with 12 LED's, 280W of power can be delivered without major heat production.
	A 48V 144W power supply found on Amazon can be connected directly to the LED's without fear of damaging them, but may cause premature failure of power supply.

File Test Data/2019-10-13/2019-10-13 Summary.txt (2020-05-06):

Goal:
	Investigate relationship between [light output & noise] and [gate & capacitor voltage]
	Potentially desctructive test budget: 1 LED

Equipment: 
	NQTRONIX Active Probe
	BK Precision Oscilloscope
	55-cm integrating sphere
	Digital multimeter
	Rev. 3 controller prototype with MIC2171-based flyback converter
	
Setup:
	Single LED strobing for 1 microsecond at various capacitor voltages (65 - 150 V) and MOSFET gate voltages (7 - 16 V)
	Oscilloscope channel 1 is connected to the active light probe
	Oscilloscope channel 2 is connected to the capacitor voltage (to measure voltage drop, allowing cacluclation of average current)
	10uF capacitor
	
Results:
	Light output -v- capacitor voltage relationship remains relatively linear between 65 V and 150 V.  There is no significant drop-off
	Gate voltage between 8 V and 16 V does not have significant effect on light output
	Gate voltage does have significant effect on light output noise, especially during turn-on.  Turn-on noise can be eliminated and turn-off noise can be reduced by lowering gate voltage.
	Gate voltage below 8 V has significant detrimental effect on light output.
	LED was not damaged during tests
	
Comments:
	The new Rev. 3 prototype controller is almost identical to the Rev. 2, except that the layout is much easier to manage.
	By coincidence, the 8 - 12 V gate voltage used by the original flash design appears to be ideal.  The Mark 2 will have a regulated gate voltage and it will likely be set somewhere in that neighbourhood.
	The 125 V capacitor voltage limit may be revisited as higher voltages appear to greatly enhance the light output.
	This test is limited by the fact that only one LED was used.  The next experiment will be identical, but with a complete bank of 3x LED's.

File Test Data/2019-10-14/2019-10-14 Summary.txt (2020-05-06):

Goal:
	Investigate relationship between [light output & noise] and [gate & capacitor voltage]
	Similar to 2019-10-13 testing, but with an entire bank of LED's (3x LED's)
	Potentially desctructive test budget: 3 LED

Equipment: 
	NQTRONIX Active Probe
	BK Precision Oscilloscope
	55-cm integrating sphere
	Digital multimeter
	Rev. 3 controller prototype with MIC2171-based flyback converter
	
Setup:
	Single LED strobing for 1 microsecond at various capacitor voltages (65 - 150 V) and MOSFET gate voltages (7 - 16 V)
	Oscilloscope channel 1 is connected to the active light probe
	Oscilloscope channel 2 is connected to the capacitor voltage (to measure voltage drop, allowing cacluclation of average current)
	
Results:
	TO BE COMPLETED
	
Comments:
	Stopped at 90 volts as light probe was clipping (2.1 volts)
	Need to build an ND filter mount for the integrating sphere
	No LED's damaged

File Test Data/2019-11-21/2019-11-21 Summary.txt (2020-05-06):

Goal:
	Test high-pass filter
	Test trigger reponse time for RISING and FALLING signals

Equipment: 
	BK Precision Oscilloscope
	Control boards x2 (S/N 002 & 003)
	
Setup:
	Upload modified firmware (4uS pulse will trigger gate for 1,000 uS)
	Connect scope channel 1 to Gate output, channel 2 to Trigger input
	Arm scope
	Perform 2x falling edge triggers by closing switch between trigger input and ground
		(microcontroller set to 1,000uS pulse output in order to test high-pass filter)
	Perform 2x rising edge triggers by opening switch between trigger input and ground
		(microcontroller set to 1,000uS pulse output in order to test high-pass filter)
	
Results:
	Falling-edge trigger delay is about 1 microsecond
	Rising-edge trigger delay is <20 microseconds
	High-pass filter is well-tuned, about 4.5 uS
	
Comments:
	Results are satisfactory
	Falling-edge triggers are preferred, perhaps look into improvements to rising edge triggering

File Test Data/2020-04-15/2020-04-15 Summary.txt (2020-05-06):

Goal:
	QA testing of five different EMCB0 rev1.2c boards
	These traces were acquired during the QA process

Equipment: 
	Siglent SDS1202X-E Oscilloscope
	EMCB0 rev1.2c Control boards x5
	
Setup:
	1us - 1 Microsecond pulse, Ch1 = Gate Driver Output, Ch2 = Microcontroller Output
	2us - 2 Microsecond pulse, Ch1 = Gate Driver Output, Ch2 = Microcontroller Output
	4us - 4 Microsecond pulse, Ch1 = Gate Driver Output, Ch2 = Microcontroller Output
	500ns - 0.5 Microsecond pulse, Ch1 = Gate Driver Output, Ch2 = Microcontroller Output
	HighPassFilterTest - 1,000 Microsecond pulse from microcontroller using modified firmware to test high-pass filter (limits pulses to 5 microseconds), Ch1 = Gate Driver Output, Ch2 = Microcontroller Output
	TriggerActiveHigh - Push-button attached to trigger input to test delay between trigger input going HIGH and flash output, CH1 = Trigger Input, Ch2 = Gate Driver Output
	TriggerActiveHigh - Push-button attached to trigger input to test delay between trigger input going LOW and flash output, CH1 = Trigger Input, Ch2 = Gate Driver Output
	
Results:
	High-pass filter varies from unit - unit between 4.5 - 5.0 microseconds
	Pulse durations are within 250 ns of described duration
	Both active-low and active-high trigger response times are 2 microseconds or less
	
Comments:
	Results are satisfactory
	8MHz clock rate is sufficient for this purpose
	Active-high triggering has improved significantly since 2019-11-21 tests due to circuitry improvements

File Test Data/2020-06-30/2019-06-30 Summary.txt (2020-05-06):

Goal:
	Test new 'Tripwire' trigger system
	This new system makes high-speed bullet photography possible if you don't have a ballistic chronograph or other fancy trigger

Equipment: 
	0.177 pellet rifle
	Edgerton MK1
	Tripwire Trigger
	
Setup:
	Connect Edgerton to Tripwire trigger
	Couple of shots @ 0 delay, another couple @ 10 millisecond delay
	
Results:
	It works!

Comments:
	Not much to say except that it works!
	Use fine-gauge wire to prevent projectile toppling

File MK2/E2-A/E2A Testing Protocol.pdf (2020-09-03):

E2A Testing Procotol 1.1.odt

# E2-A Strobe Testing Protocol

## Tyler Gerritsen – 1.1

## Description

Prior to commissioning an E2A microsecond LED flash, quality checks must be performed to ensure no issues or faulty components are present which may reduce the unit’s lifespan. Relying on experience with the destructive testing of dozens of LED’s, the tests are designed to identify defects and early failures while not reducing the lifespan.

## Tools & Instruments Required

- Oscilloscope
- Digital Multimeter
- Active Light Probe
- Camera with Video Record Function
- Lab PSU (2.5V – 6.0V, 2A output)
- FTDI RS-232 adapter

## EMCB1 (Main Control Board)

1. Board can be programmed (FTDI adapter). Check:
2. Board can be powered by 2.5 - 6 v (Lab PSU). Check:
3. Board IO functional (encoder, display, audio). Check:
4. Connect high-voltage converter, set to 120V, calibrate firmware. Check:
5. Confirm 130V output into board, 120V @ Zener (multimeter). Check:
6. Confirm capacitors charge 0V – 120V in 2 seconds or less. Check:
7. Confirm capacitors discharge 120V – 36V in 2 seconds or less. Check:
8. Test high-pass filter (CH1 -> Gate, CH2 -> microcontroller output, 1us/div, 0us offset). Save trace:

## ECC0 (Capacitor Charger)

9. Using oscilloscope, measure the voltage at the flyback converter’s switch pad. Confirm switch overshoot does not exceed 30V @ MIC3172. Save traces with input voltages of 3.0V and 6.0V:
10. Set capacitor anode voltage to 120V, TC4452 input voltage to 12.8V. Record full unit current draw @ 3.0V, 4V.0, 6.0V.:
11. Install charged batteries. Leave unit on and capacitors charged for 2 hours. Confirm voltages have not deviated. Record pre-test and post-test battery voltage, TC4452 input voltage, and Capacitor Anode voltage:
| Time | Input Voltage | TC4452 Voltage | Capacitor Anode Voltage
Start
End

## Strobe Testing

Mount the unit on the integrating sphere. Install a 2-stop ND filter. Oscilloscope CH2 connects to the active light probe.
1. Measure the light output @ 0.5us, 1us, 2us, 4us. Save traces.
2. Oscilloscope CH1 – trigger input, test delay Active-Low (push to trigger). Save trace:
3. Oscilloscope CH1 – trigger input, test delay Active-High (release to trigger). Save trace:
4. Set the strobe to 500ns strobe duration and 6x consecutive strobes. Test the following matrix. After each test, measure the time between strobes using the oscilloscope’s Measure Frequency function and a measurement gate. Save Traces:
Delay between strobes | Total strobe time | Timebase | Tolerance | All Strobes Within Tolerance?
250 us | 1,250 us | 100us | +/- 6 us
500 us | 2,500 us | 200us | +/- 12 us
750 us | 3,750 us | 500us | +/- 19 us
1,000 us | 5,000 us | 500us | +/- 25 us
1,250 us | 6,250 us | 500us | +/- 0.03 ms
1,500 us | 7,500 us | 1ms | +/- 0.04 ms

1,750 us | 8,750 us | 1ms | +/- 0.04 ms
2,000 us | 10,000 us | 1ms | +/- 0.05 ms
5. Test the following matrix. Total strobes: 7,400x. Total testing time: 900 seconds (15 minutes). Total illumination time: 14.25 milliseconds. Video record the oscilloscope @ 30fps and note whether LED’s appeared damaged or have completely failed.
Duration | Count | Rate | Reps | Rate | Timebase | (P)ass / (D)amage / (F)ailure
0.5us, 1x | 1,000x | 8Hz | 200ns, -1us
1us, 1x | 1,000x | 8Hz | 200ns, -1us
2us, 1x | 1,000x | 8Hz | 200ns, -1us
4us, 1x | 1,000x | 8Hz | 500ns, -3us
0.5us, 6x, 250us | 250 | 2Hz | 100us, -600us
1us, 4x, 250us | 250 | 2Hz | 100us, -600us
2us, 4x, 1,000us | 250 | 2Hz | 500us, -3ms
4us, 3x, 1,000us | 250 | 2Hz | 200us, -1.2ms
6. Oscilloscope CH1 – ATMEGA328P pin 7, CH2 – ATMEGA328P pin 20 (vcc pins), test 0.5us, 1us, 2us, 4us strboe. Save traces.
7. Measure the light output @ 0.5us, 1us, 2us, 4us. Light levels must meet the pre-testing levels measured during step 1. Save traces.

## Information & Signature

Name | Date
Unit S/N | EMCB1 S/N
ECC0 S/N | Faceplate S/N

Signature

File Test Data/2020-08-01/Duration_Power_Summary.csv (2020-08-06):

Nikon SB-800
Power: | LO |  |  | 1/128 |  |  | 1/64 |  |  |  |  | 1/32
Test | 1 | 2 | 3 | 4 | 5 | 6 | 7 | 8 | 9 | 10 |  | 11
Max Voltage | 1.09 | 1.17 | 1.19 | 1.46 | 1.51 | 1.5 | 1.63 | 1.54 | 1.61 | 1.62 |  | 1.85
T0.5 (us) | 39 | 41 | 41 | 61 | 63 | 62 | 95 | 97 | 92 | 96 |  | 158
T0.1 (us) | 74 | 79 | 79 | 103 | 108 | 105 | 143 | 144 | 142 | 143 |  | 193
Yongnuo YN-460 II
Power: | 1/128 |  |  | 1/64 |  |  | 1/32
Test | 12 | 13 | 14 | 15 | 16 | 17 | 18
Max Voltage | 1.15 | 1.12 | 1.08 | 1.49 | 1.54 | 1.51 | 1.83
T0.5 (us) | 23 | 23 | 25 | 31 | 30 | 31 | 48
T0.1 (us) | 52 | 51 | 52 | 64 | 64 | 65 | 84
Canon 430EX-II
Power: | LO |  |  | 1/128 |  |  | 1/64 |  |  |  |  |  |  | 1/32 |  |  | 1/16
Test | 19 | 20 | 21 | 22 | 23 | 24 | 25 | 26 | 27 | 28 | 29 | 30 |  | 31 | 32 | 33 | 34
Max Voltage | 0.52 | 0.54 | 0.53 | 0.84 | 0.84 | 0.84 | 1.11 | 1.19 | 1.18 | 1.19 | 1.19 | 1.2 |  | 1.51 | 1.55 | 1.51 | 1.79
T0.5 (us) | 26 | 26 | 25 | 34 | 34 | 33 | 42 | 45 | 47 | 46 | 45 | 45 |  | 66 | 67 | 66 | 93
T0.1 (us) | 55 | 57 | 56 | 70 | 71 | 71 | 87 | 90 | 94 | 93 | 92 | 92 |  | 120 | 121 | 120 | 154
Nikon SB-910
Power: | LO |  |  | 1/128 |  |  | 1/64 |  |  |  | 1/32 |  |  |  | 1/16
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

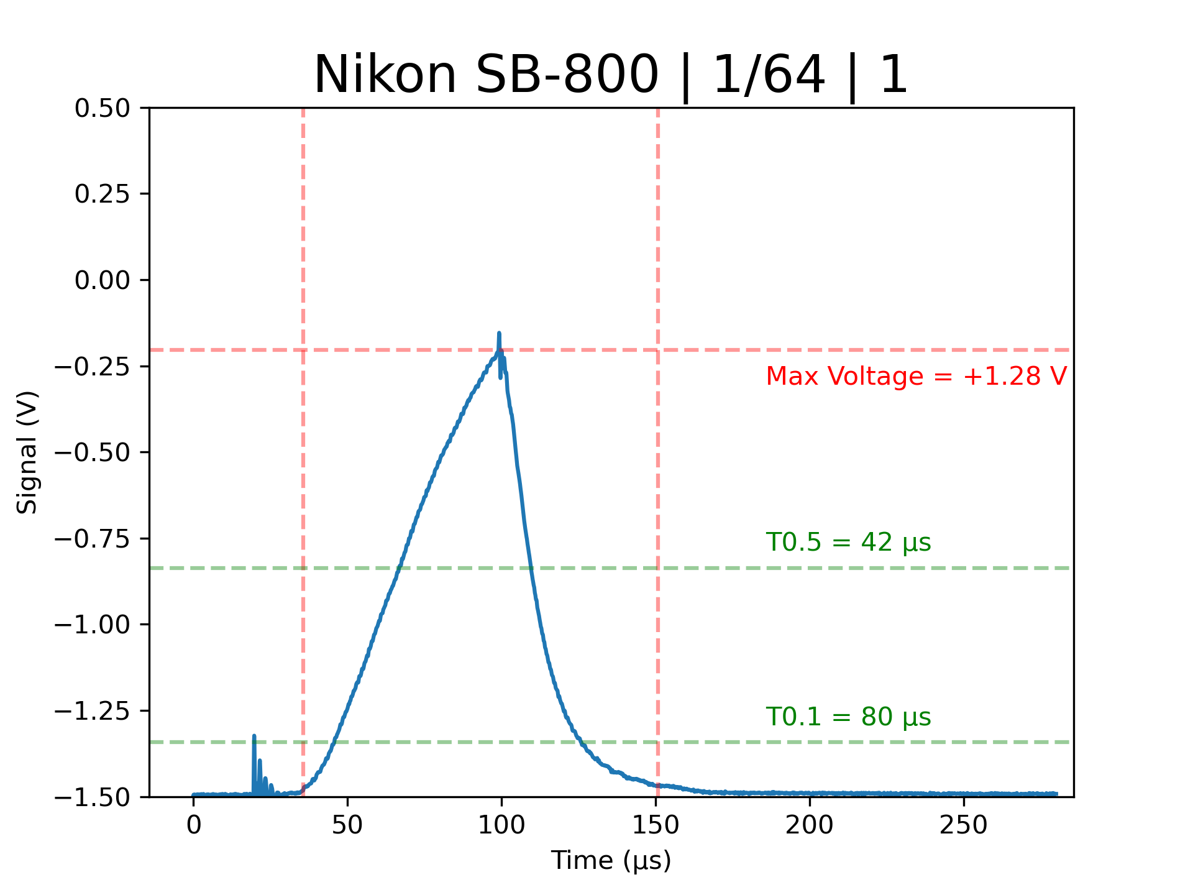
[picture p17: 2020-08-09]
Test Data/2020-08-01/105mm Test/072_Nikon SB-800_64_1.png

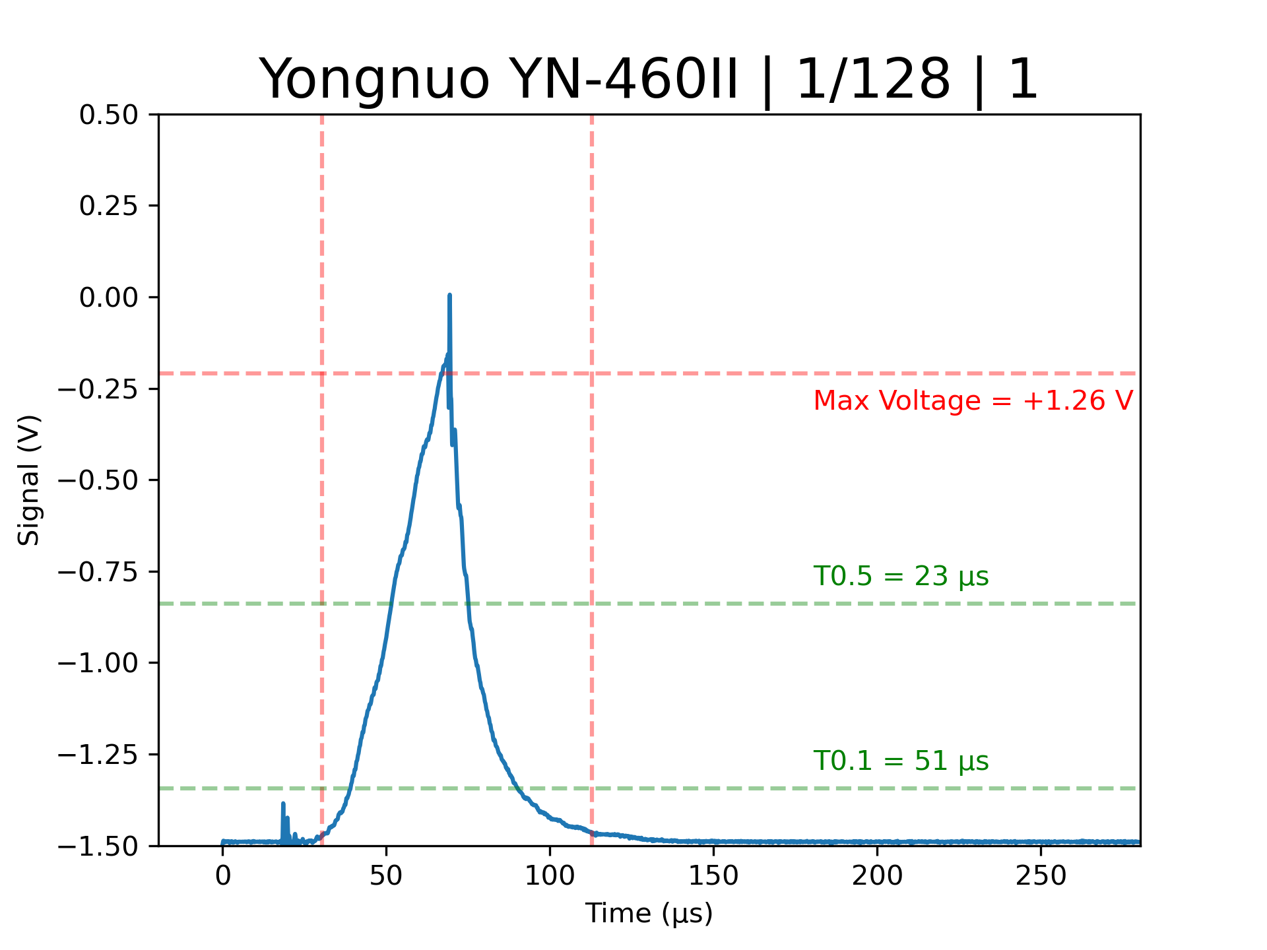
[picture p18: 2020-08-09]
Test Data/2020-08-01/Yongnuo Test/088_Yongnuo YN-460II_128_1.png

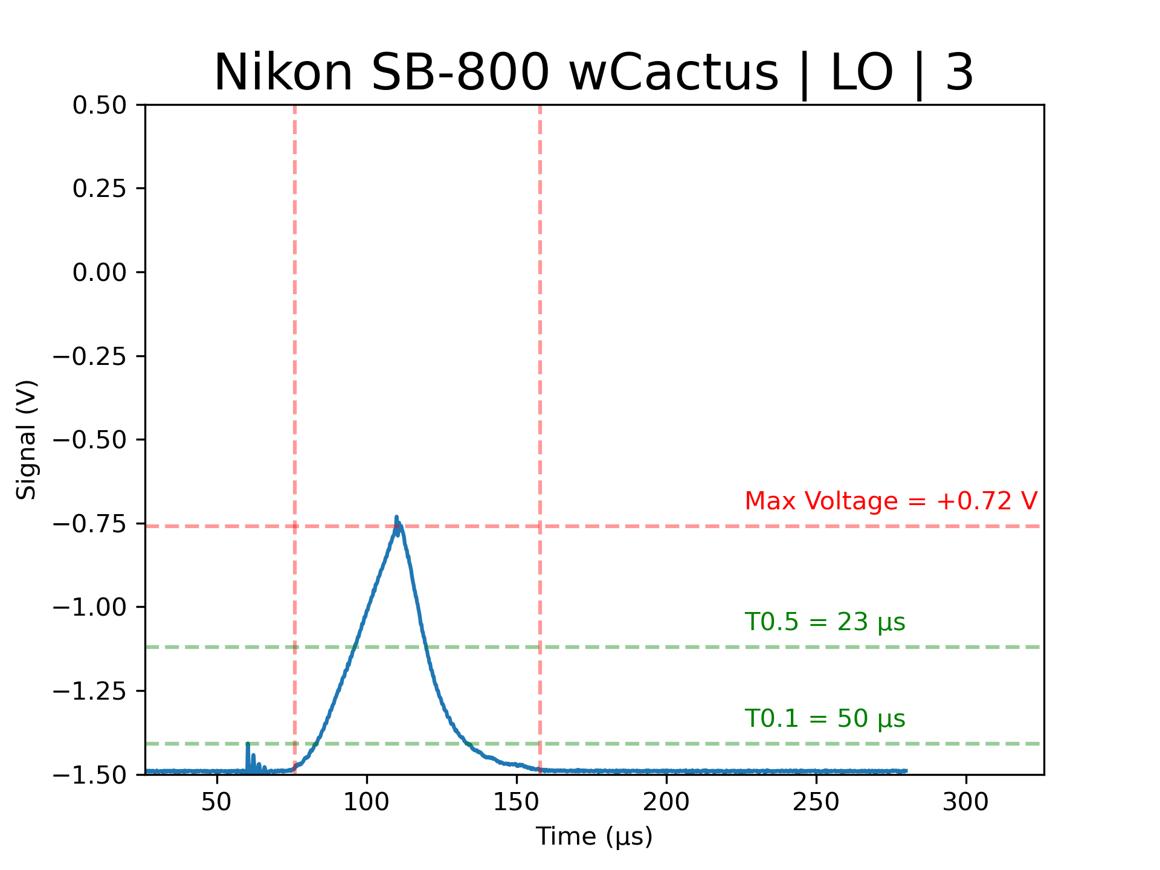
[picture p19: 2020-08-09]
Test Data/2020-08-01/Traces/054_Nikon SB-800 wCactus_LO_3.png

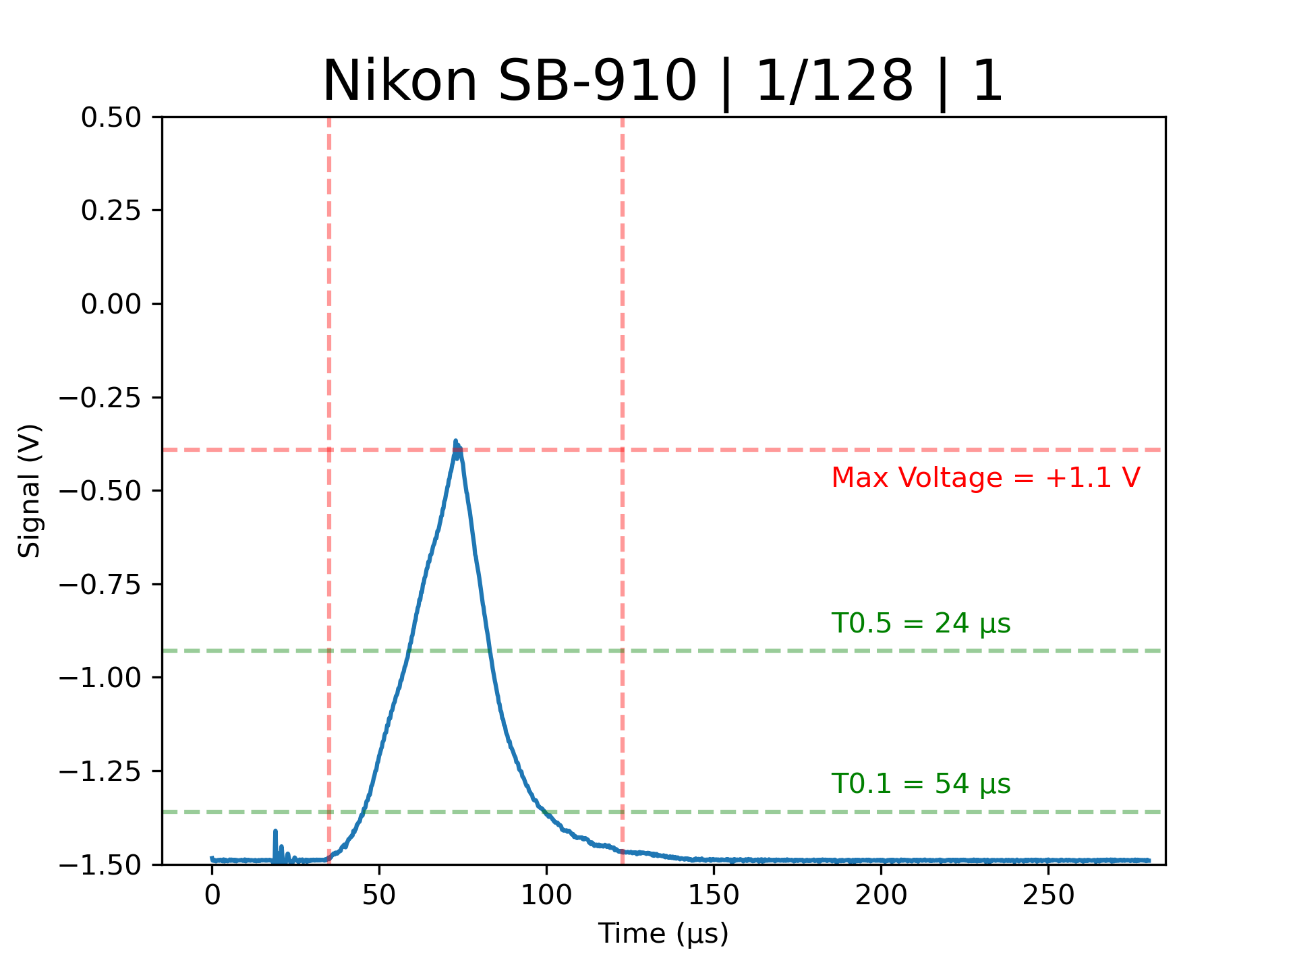
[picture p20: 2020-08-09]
Test Data/2020-08-01/Traces/105_Nikon SB-910_128_1.png

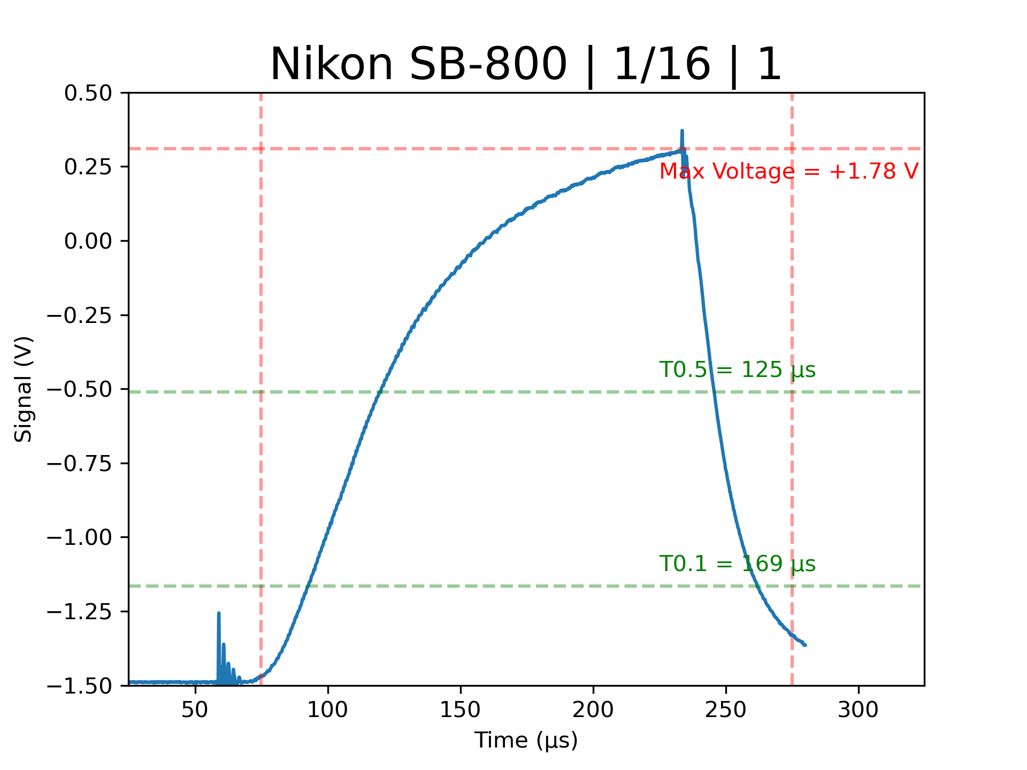
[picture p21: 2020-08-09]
Test Data/2020-08-01/Traces/068_Nikon SB-800_16_1.png

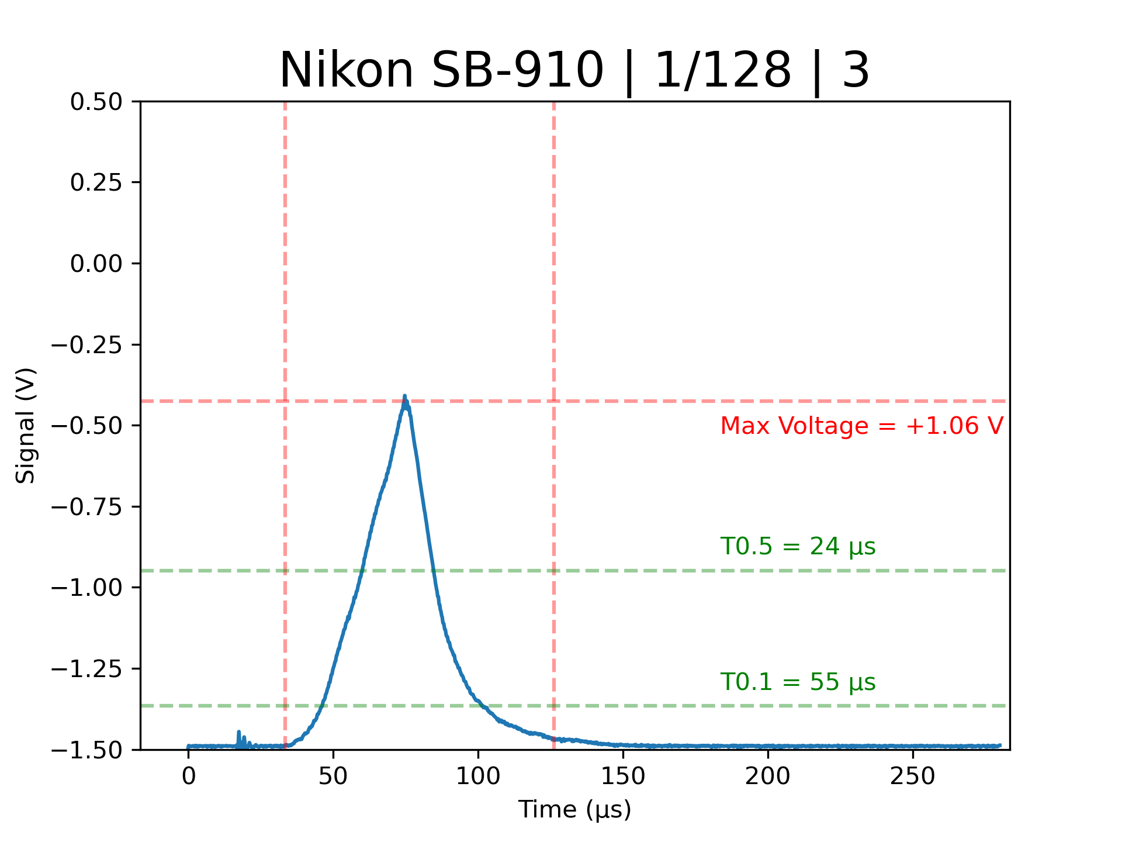
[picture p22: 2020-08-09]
Test Data/2020-08-01/Traces/107_Nikon SB-910_128_3.png

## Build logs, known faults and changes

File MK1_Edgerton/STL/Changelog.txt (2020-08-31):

1.0  2019-05-15
	Initial Release

1.1	2019-06-07
	Battery door enlarged, Case modified accordingly
	More allowance for TM1637 display
	Battery slot diameters enlarged slightly
	Relay mount removed
	Added brand-new template design
	Increased LED slot size, rounded corners
	
1.2	2020-03-20
	Changed control board mount

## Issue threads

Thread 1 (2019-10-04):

Inverted pinout on boost converter?

capaulson, 2019-10-04:
It looks like the pinout on J6 may be incorrect. In+ is tied to GND and In- to 8-12V.

td0g, 2019-10-04:
You're right.  I will fix that ASAP..

td0g, 2019-10-05:
Corrected.  Thanks.

Closed 2019-10-05.

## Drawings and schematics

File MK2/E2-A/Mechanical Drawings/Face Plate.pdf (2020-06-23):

4

3

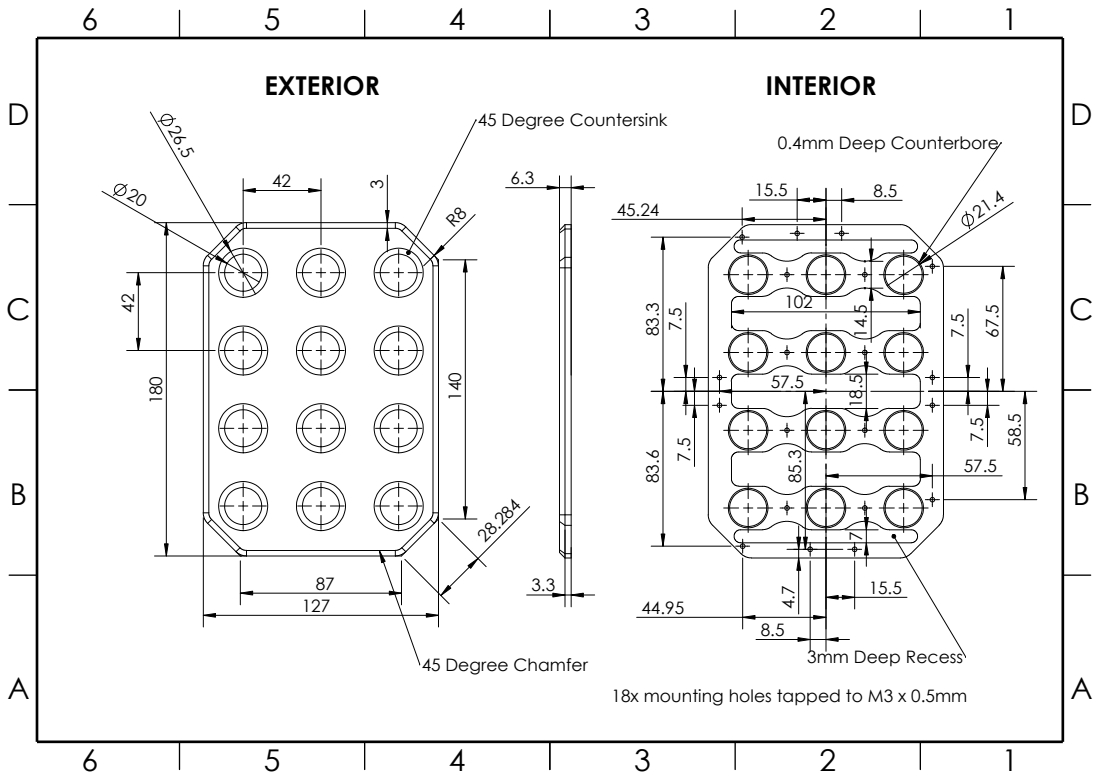
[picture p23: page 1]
EXTERIOR; INTERIOR; 0.4mm Deep Counterbore; 3mm Deep Recess; 45 Degree Countersink; 45 Degree Chamfer

18x mounting holes tapped to M3 x 0.5mm

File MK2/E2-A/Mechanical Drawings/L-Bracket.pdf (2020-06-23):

2

D D

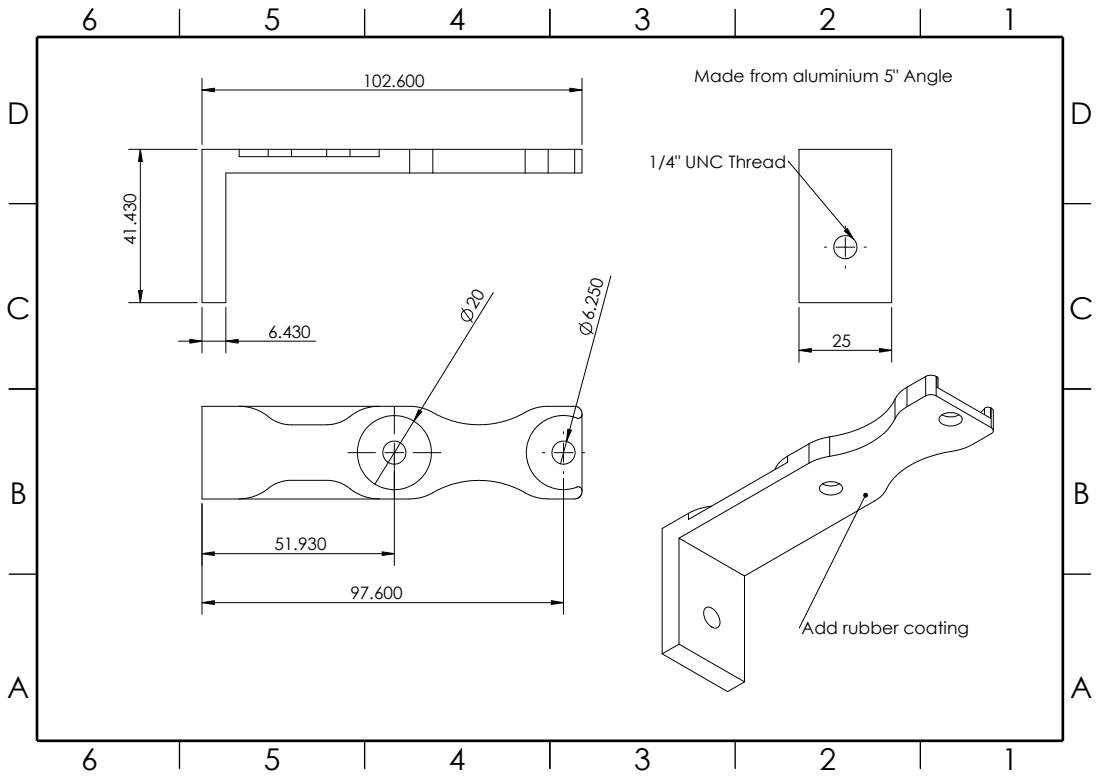
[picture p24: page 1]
1/4" UNC Thread

Made from aluminium 5" Angle

Add rubber coating

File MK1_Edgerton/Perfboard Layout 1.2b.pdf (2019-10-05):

1 | 2 | 3 | 4 | 5 | 6 | 7 | 8

A

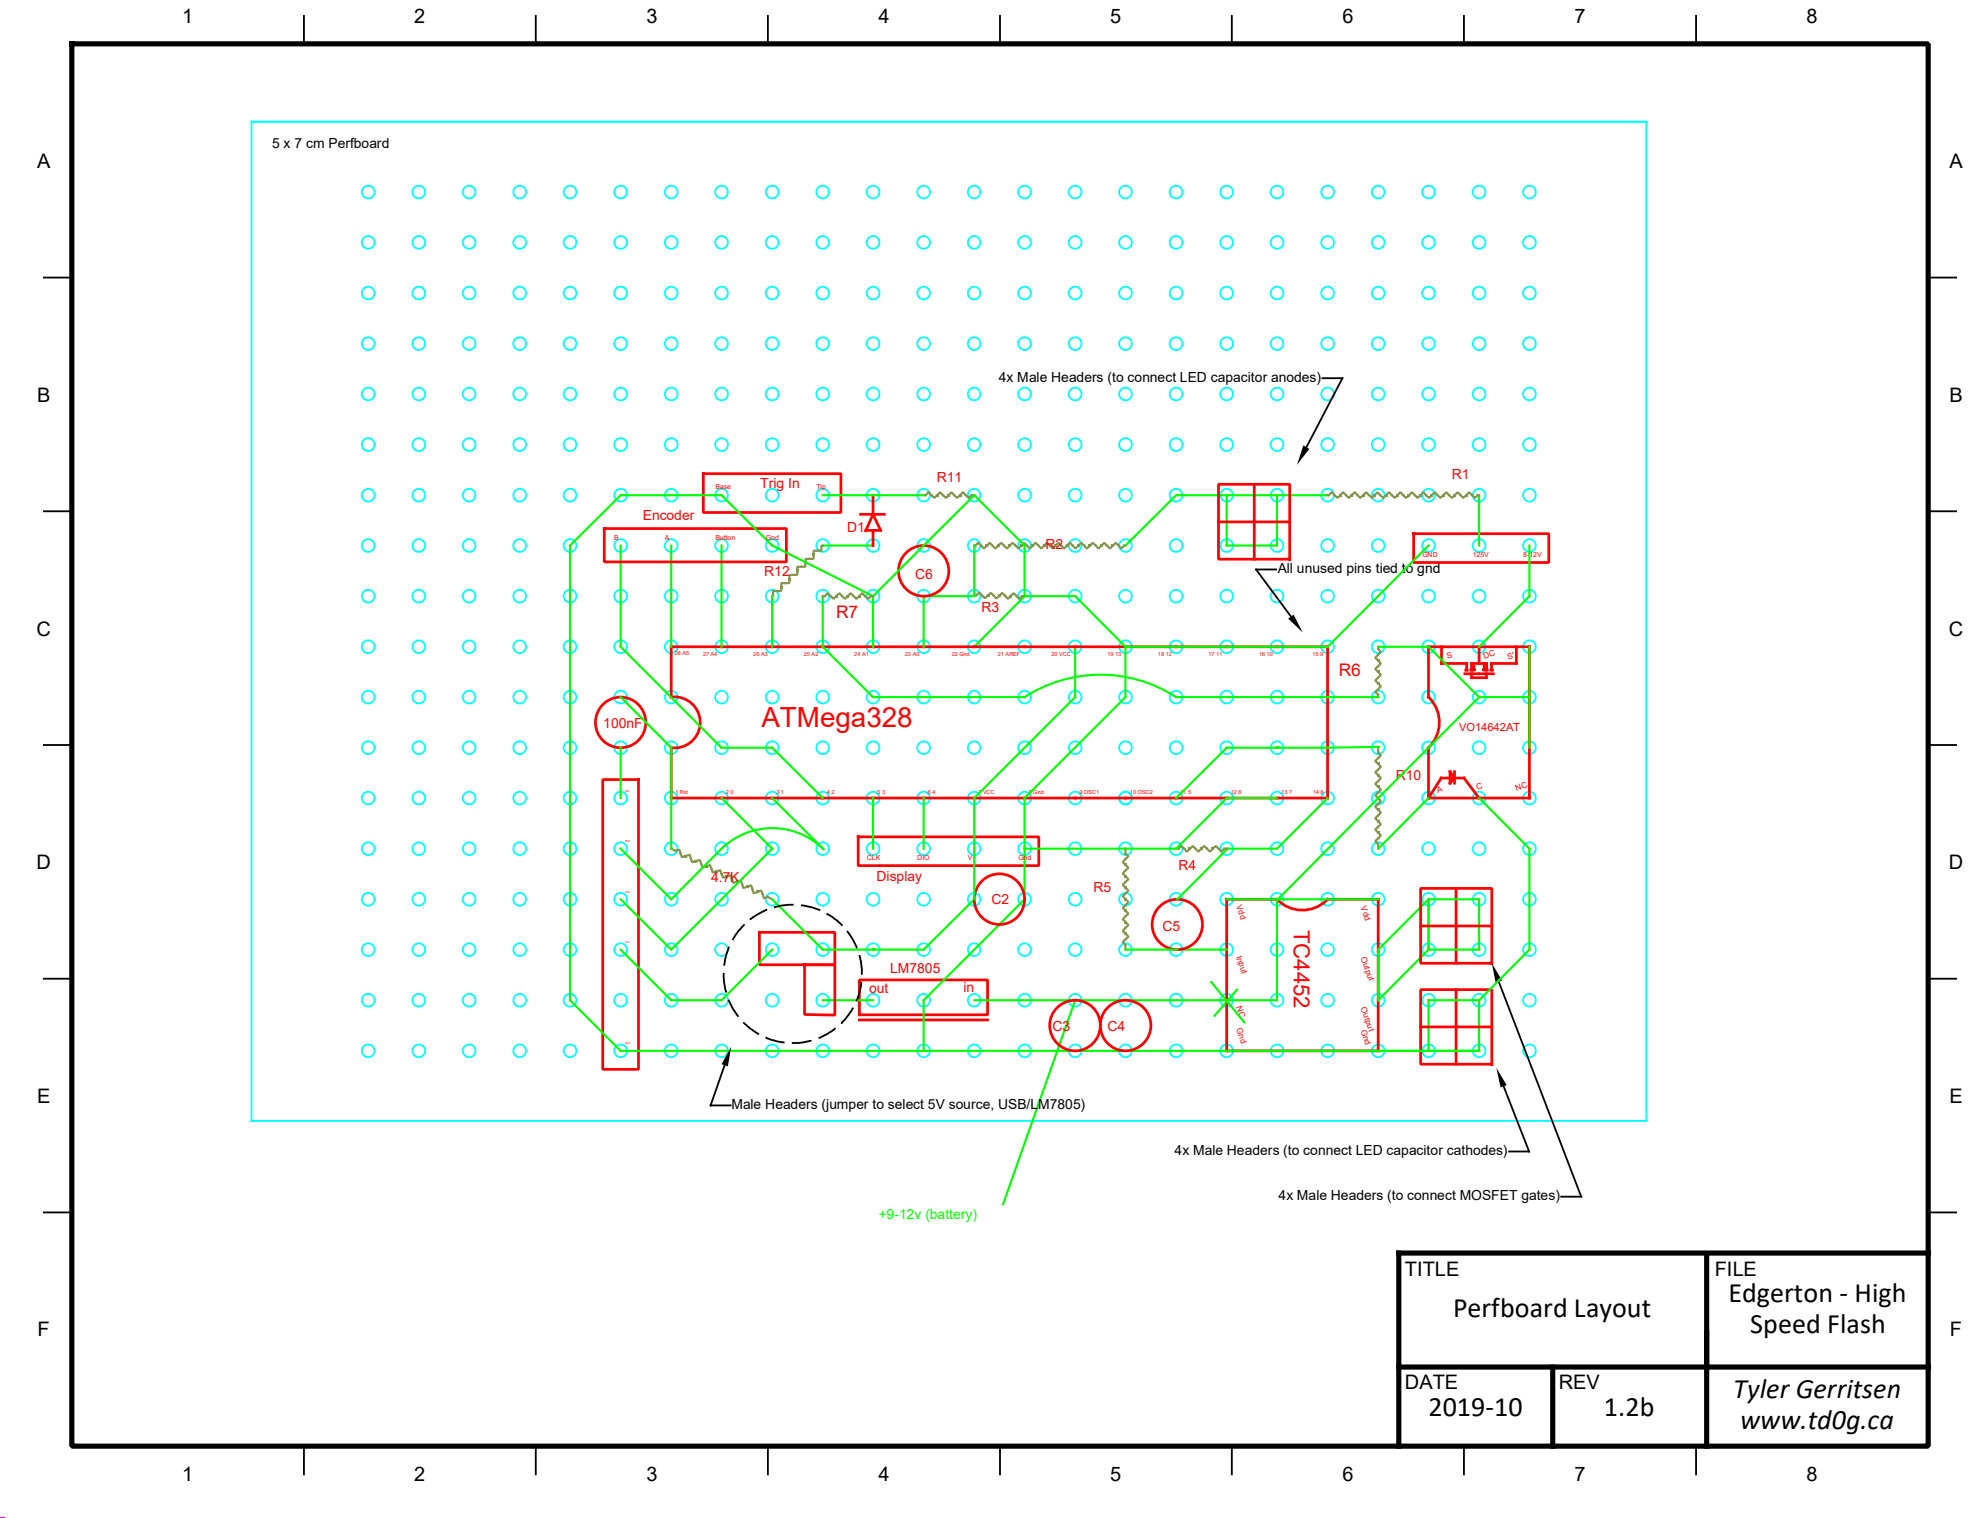
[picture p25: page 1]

4x Male Headers (to connect LED capacitor anodes)

All unused pins tied to gnd

Male Headers (jumper to select 5V source, USB/LM7805)

4x Male Headers (to connect LED capacitor cathodes)

4x Male Headers (to connect MOSFET gates)

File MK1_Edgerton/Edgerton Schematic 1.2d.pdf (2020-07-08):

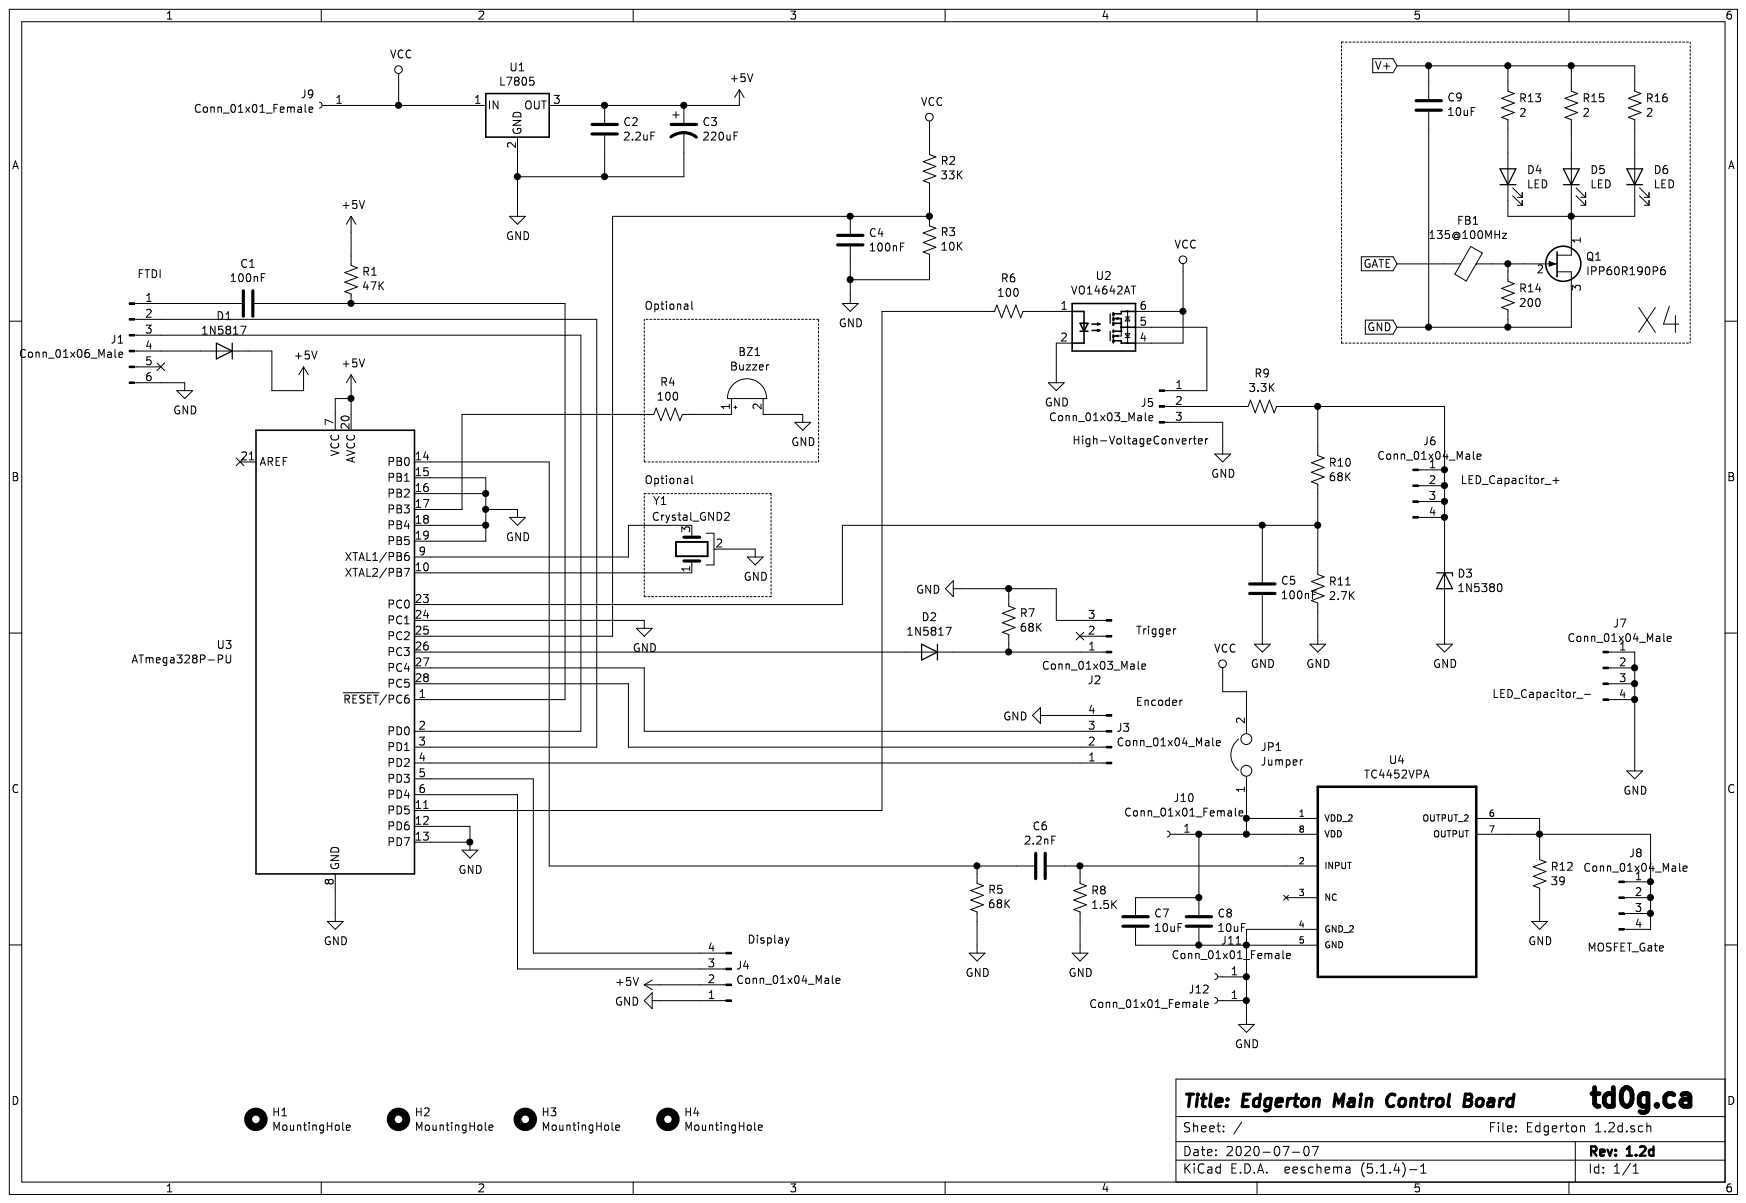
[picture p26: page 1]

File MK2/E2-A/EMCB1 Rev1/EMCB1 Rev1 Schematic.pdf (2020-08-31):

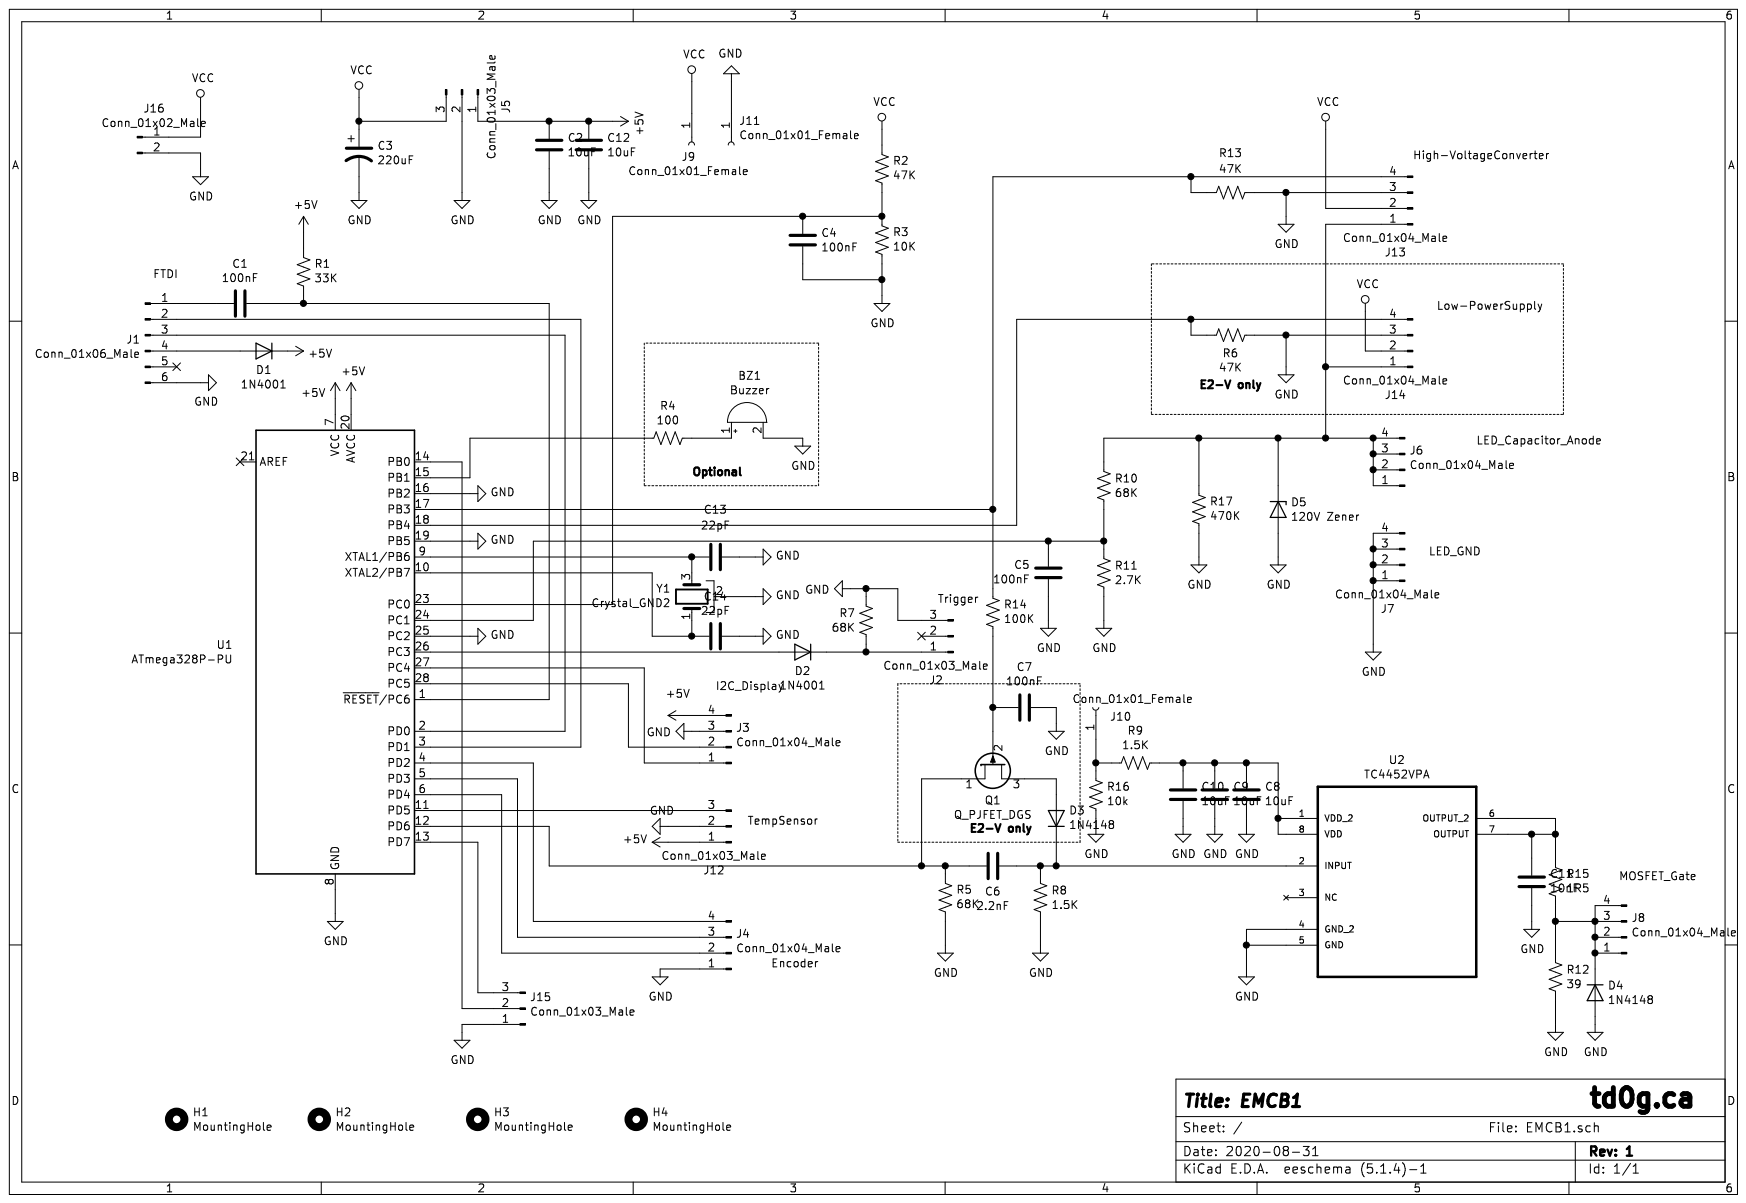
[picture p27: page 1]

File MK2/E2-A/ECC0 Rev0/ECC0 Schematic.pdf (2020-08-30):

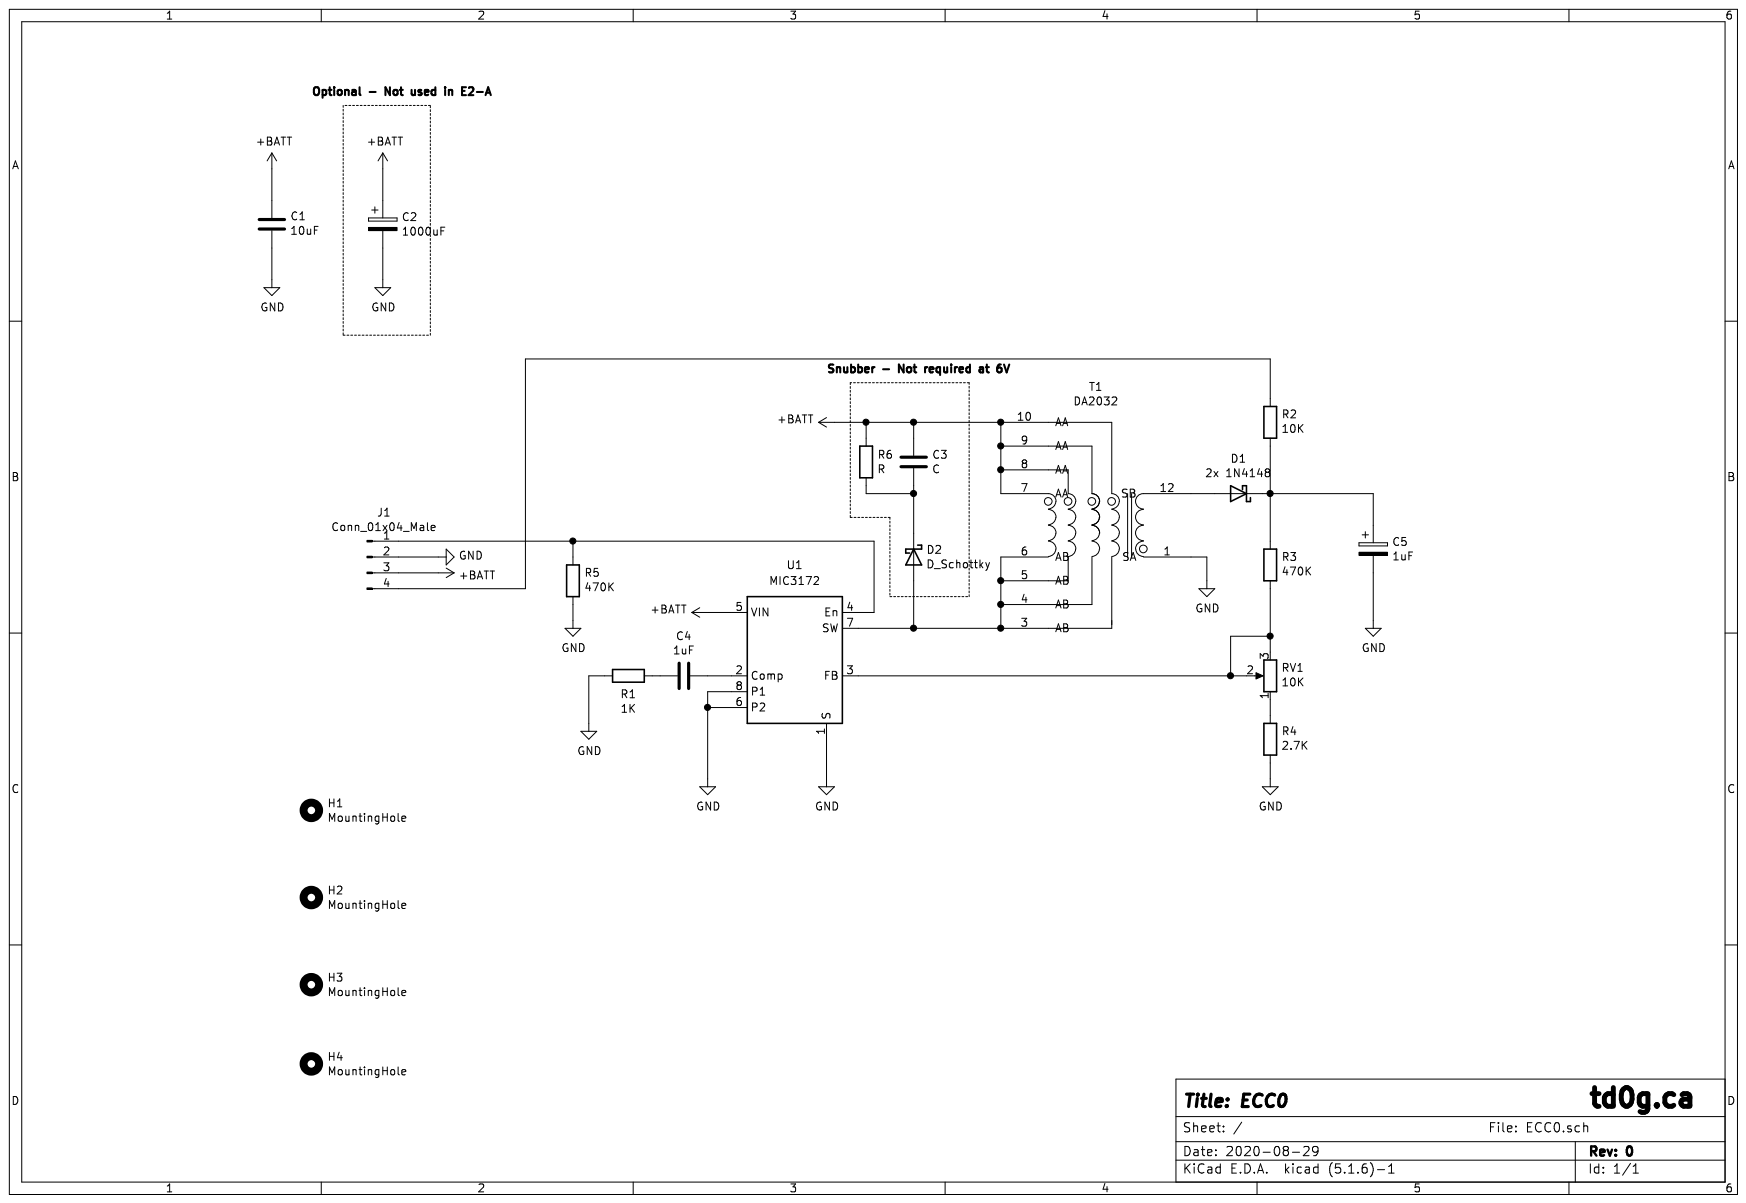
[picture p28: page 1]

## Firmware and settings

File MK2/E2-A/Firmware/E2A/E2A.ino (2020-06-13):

  #include <Wire.h>
  #include <Adafruit_GFX.h>
  #include <Adafruit_SSD1306.h>
  #include <EEPROM.h>
  
  #define SCREEN_WIDTH 128 // OLED display width, in pixels
  #define SCREEN_HEIGHT 64 // OLED display height, in pixels
  
  #define SOUND
  
  #define SUBMODEL E2A
  
  #define BUTTON_LONGHOLD 600
  #define BUTTON_DEBOUNCE 25
  // Declaration for an SSD1306 display connected to I2C (SDA, SCL pins)
  #define OLED_RESET     4 // Reset pin # (or -1 if sharing Arduino reset pin)
  Adafruit_SSD1306 display(SCREEN_WIDTH, SCREEN_HEIGHT, &Wire, OLED_RESET);

  #define EEPROM_BATTERY_CAL_2V 82
  #define EEPROM_BATTERY_CAL_6V 209
  #define EEPROM_ANODE_CAL 150
  #define BUTTON_PIN 2
  #define ENCODER_A_PIN 3
  #define ENCODER_B_PIN 4
  #define BUTTON_PRESSED (!(PIND & 0b00000100))
  #define BUTTON_NOT_PRESSED PIND & 0b00000100
  #define ENCODER_STATE ((PIND >> 3) & 0b00000011)
  #define HIGH_POWER_BUCK_CONTROL_PIN 5 //Output Low
  #define FLASH_PIN 6 //Output Low
  #define FLASH_ON PORTD = 0b01011100 //Keep encoder/button pullups on
  #define FLASH_OFF PORTD = 0b00011100 //Keep encoder/button pullups on
  #define HIGH_POWER_BUCK_CONTROL_A_PIN 7 //Output Low
  #define HIGH_POWER_BUCK_CONTROL_B_PIN 8 //Output Low
  #define SOUND_PIN 9 //Output Low
  #define HIGH_VOLTAGE_CONTROL_PIN 11 //Output Low
  #define LOW_POWER_BOOST_CONTROL_PIN 12  //Output Low
  #define INPUT_VOLTAGE_PIN 14 //Input 1/4.3 voltage divider
  #define CAPACITOR_VOLTAGE_PIN 15 //Input 2.7/70.7 voltage divider
  #define TRIGGER_PIN 17  //Input
  #define DISPLAY_SDA_PIN 18
  #define DISPLAY_SCL_PIN 19
  
  #define TRIGGER_HIGH (PINC & 0b00001000)
  #define TRIGGER_HIGH_BUTTON_NOT_PRESSED (PINC & 0b00011000)
  #define TRIGGER_LOW (!(PINC & 0b00001000))
  #define TRIGGER_LOW_BUTTON_NOT_PRESSED (!(PINC & 0b00001000) && (PINC & 0b00010000))

  #define MAX_PULSES 6
  #define MAX_PULSE_RATE 7
  #define MIN_ANODE_VOLTAGE 40
  #define MIN_BATTERY_VOLTAGE 2.95

  #define EEPROM_BATTERY_CAL_2V 50
  #define EEPROM_BATTERY_CAL_6V 100
  #define EEPROM_ANODE_CAL 150
  #define SERIAL_NUMBER 1
  #define FIRMWARE_VERSION "1.0"

  #define HIGH_VOLT_ON digitalWrite(HIGH_VOLTAGE_CONTROL_PIN, 1)
  #define HIGH_VOLT_OFF digitalWrite(HIGH_VOLTAGE_CONTROL_PIN, 0)
  
  //pulseDuration Calibration
  #define NOP __asm__ __volatile__ ("nop\n\t")
  #define DELAY_500_NS NOP; NOP; NOP; NOP; NOP
  #define DELAY_1US DELAY_500_NS; DELAY_500_NS; NOP; NOP; NOP
  #define DELAY_2US DELAY_1US; DELAY_1US; NOP; NOP; NOP
  #define DELAY_4US DELAY_2US; DELAY_2US; NOP; NOP; NOP

  #define TONE_A 3520 //Good Volume
  #define TONE_A_S 3729 //Good Volume
  #define TONE_B 3951 //Good Volume
  #define TONE_C 4186 //Good Volume
  #define TONE_C_S 4435
  #define TONE_D 4698
  #define TONE_D_S 4978
  #define TONE_E 5274
  #define TONE_F 5588
  #define TONE_G 6272

  #define PRINT_MICROSECOND display.write(230); display.print("s");

  byte menuPosition = 0b10000000;
  byte modellingLamp = 0;
  byte modellingLampLast = 1;
  byte pulseDuration = 1;
  unsigned int flashDelay = 0;
  byte pulseCount = 1;
  unsigned int pulseRate = 1;
  int temperature;
  byte activeTrigger;
  unsigned int delayTime[8] = {4000, 8000, 12000, 16000, 20000, 24000, 28000, 32000};
  byte soundOn = 1;
  byte flipDisplay = 1;
  byte reverseEncoder = 0;
  
  unsigned int lowVoltAdc = 0;
  unsigned int highVoltAdc = 0;
  unsigned int calBattery2V;
  unsigned int calBattery6V;
  byte calAnode;
  byte voltageSafetyOverride = 0;


void setup() {
  digitalWrite(FLASH_PIN, 0);
  pinMode(FLASH_PIN, OUTPUT);
  pinMode(LOW_POWER_BOOST_CONTROL_PIN, OUTPUT);
  pinMode(HIGH_VOLTAGE_CONTROL_PIN, OUTPUT);
  pinMode(ENCODER_A_PIN, INPUT_PULLUP);
  pinMode(ENCODER_B_PIN, INPUT_PULLUP);
  pinMode(BUTTON_PIN, INPUT_PULLUP);
  pinMode(SOUND_PIN, OUTPUT);
  pinMode(TRIGGER_PIN, INPUT_PULLUP);
  Serial.begin(9600);
  display.begin(SSD1306_SWITCHCAPVCC, 0x3C);
  importEEPROM();
  if (flipDisplay) display.setRotation(2);
  Serial.println("E2|A Ready");
  soundStartup();
  //ADC & UI
  ADCSRA =  bit (ADEN);   // turn ADC on
  ADCSRA |= bit (ADPS0) | bit (ADPS1) | bit (ADPS2);
  
//Timer1 for multi-strobe
  TCCR1A = 0;
  TCCR1B = 0b00000001;         // div1 = 1/16us per increment, 16-bit normal mode
  while (BUTTON_PRESSED && millis() < 5000){
    runDisplay();
    runTrigger();
    analogReadAll();
  }
  if (BUTTON_PRESSED){
    initMenu();
  }
}

void loop(){
  runDisplay();
  runUI();
  runTrigger();
  analogReadAll();
}




/*
  // Draw a single pixel in white
  display.drawPixel(10, 10, SSD1306_WHITE);


void testdrawline() {
  int16_t i;

  display.clearDisplay(); // Clear display buffer

  for(i=0; i<display.width(); i+=4) {
    display.drawLine(0, 0, i, display.height()-1, SSD1306_WHITE);
    display.display(); // Update screen with each newly-drawn line
    delay(1);
  }
  for(i=0; i<display.height(); i+=4) {
    display.drawLine(0, 0, display.width()-1, i, SSD1306_WHITE);
    display.display();
    delay(1);
  }
  delay(250);

  display.clearDisplay();

  for(i=0; i<display.width(); i+=4) {
    display.drawLine(0, display.height()-1, i, 0, SSD1306_WHITE);
    display.display();
    delay(1);
  }
  for(i=display.height()-1; i>=0; i-=4) {
    display.drawLine(0, display.height()-1, display.width()-1, i, SSD1306_WHITE);
    display.display();
    delay(1);
  }
  delay(250);

  display.clearDisplay();

  for(i=display.width()-1; i>=0; i-=4) {
    display.drawLine(display.width()-1, display.height()-1, i, 0, SSD1306_WHITE);
    display.display();
    delay(1);
  }
  for(i=display.height()-1; i>=0; i-=4) {
    display.drawLine(display.width()-1, display.height()-1, 0, i, SSD1306_WHITE);
    display.display();
    delay(1);
  }
  delay(250);

  display.clearDisplay();

  for(i=0; i<display.height(); i+=4) {
    display.drawLine(display.width()-1, 0, 0, i, SSD1306_WHITE);
    display.display();
    delay(1);
  }
  for(i=0; i<display.width(); i+=4) {
    display.drawLine(display.width()-1, 0, i, display.height()-1, SSD1306_WHITE);
    display.display();
    delay(1);
  }

  delay(2000); // Pause for 2 seconds
}

void testdrawrect(void) {
  display.clearDisplay();

  for(int16_t i=0; i<display.height()/2; i+=2) {
    display.drawRect(i, i, display.width()-2*i, display.height()-2*i, SSD1306_WHITE);
    display.display(); // Update screen with each newly-drawn rectangle
    delay(1);
  }

  delay(2000);
}

void testfillrect(void) {
  display.clearDisplay();

  for(int16_t i=0; i<display.height()/2; i+=3) {
    // The INVERSE color is used so rectangles alternate white/black
    display.fillRect(i, i, display.width()-i*2, display.height()-i*2, SSD1306_INVERSE);
    display.display(); // Update screen with each newly-drawn rectangle
    delay(1);
  }

  delay(2000);
}

void testdrawcircle(void) {
  display.clearDisplay();

  for(int16_t i=0; i<max(display.width(),display.height())/2; i+=2) {
    display.drawCircle(display.width()/2, display.height()/2, i, SSD1306_WHITE);
    display.display();
    delay(1);
  }

  delay(2000);
}

void testfillcircle(void) {
  display.clearDisplay();

  for(int16_t i=max(display.width(),display.height())/2; i>0; i-=3) {
    // The INVERSE color is used so circles alternate white/black
    display.fillCircle(display.width() / 2, display.height() / 2, i, SSD1306_INVERSE);
    display.display(); // Update screen with each newly-drawn circle
    delay(1);
  }

  delay(2000);
}

void testdrawroundrect(void) {
  display.clearDisplay();

  for(int16_t i=0; i<display.height()/2-2; i+=2) {
    display.drawRoundRect(i, i, display.width()-2*i, display.height()-2*i,
      display.height()/4, SSD1306_WHITE);
    display.display();
    delay(1);
  }

  delay(2000);
}

void testfillroundrect(void) {
  display.clearDisplay();

  for(int16_t i=0; i<display.height()/2-2; i+=2) {
    // The INVERSE color is used so round-rects alternate white/black
    display.fillRoundRect(i, i, display.width()-2*i, display.height()-2*i,
      display.height()/4, SSD1306_INVERSE);
    display.display();
    delay(1);
  }

  delay(2000);
}

void testdrawtriangle(void) {
  display.clearDisplay();

  for(int16_t i=0; i<max(display.width(),display.height())/2; i+=5) {
    display.drawTriangle(
      display.width()/2  , display.height()/2-i,
      display.width()/2-i, display.height()/2+i,
      display.width()/2+i, display.height()/2+i, SSD1306_WHITE);
    display.display();
    delay(1);
  }

  delay(2000);
}

void testfilltriangle(void) {
  display.clearDisplay();

  for(int16_t i=max(display.width(),display.height())/2; i>0; i-=5) {
    // The INVERSE color is used so triangles alternate white/black
    display.fillTriangle(
      display.width()/2  , display.height()/2-i,
      display.width()/2-i, display.height()/2+i,
      display.width()/2+i, display.height()/2+i, SSD1306_INVERSE);
    display.display();
    delay(1);
  }

  delay(2000);
}

void testdrawchar(void) {
  display.clearDisplay();

  display.setTextSize(1);      // Normal 1:1 pixel scale
  display.setTextColor(SSD1306_WHITE); // Draw white text
  display.setCursor(0, 0);     // Start at top-left corner
  display.cp437(true);         // Use full 256 char 'Code Page 437' font

  // Not all the characters will fit on the display. This is normal.
  // Library will draw what it can and the rest will be clipped.
  for(int16_t i=0; i<256; i++) {
    if(i == '\n') display.write(' ');
    else          display.write(i);
  }

  display.display();
  delay(2000);
}

void testdrawstyles(void) {
  display.clearDisplay();

  display.setTextSize(1);             // Normal 1:1 pixel scale
  display.setTextColor(SSD1306_WHITE);        // Draw white text
  display.setCursor(0,0);             // Start at top-left corner
  display.println(F("Hello, world!"));

  display.setTextColor(SSD1306_BLACK, SSD1306_WHITE); // Draw 'inverse' text
  display.println(3.141592);

  display.setTextSize(2);             // Draw 2X-scale text
  display.setTextColor(SSD1306_WHITE);
  display.print(F("0x")); display.println(0xDEADBEEF, HEX);

  display.display();
  delay(2000);
}

void testscrolltext(void) {
  display.clearDisplay();

  display.setTextSize(2); // Draw 2X-scale text
  display.setTextColor(SSD1306_WHITE);
  display.setCursor(10, 0);
  display.println(F("scroll"));
  display.display();      // Show initial text
  delay(100);

  // Scroll in various directions, pausing in-between:
  display.startscrollright(0x00, 0x0F);
  delay(2000);
  display.stopscroll();
  delay(1000);
  display.startscrollleft(0x00, 0x0F);
  delay(2000);
  display.stopscroll();
  delay(1000);
  display.startscrolldiagright(0x00, 0x07);
  delay(2000);
  display.startscrolldiagleft(0x00, 0x07);
  delay(2000);
  display.stopscroll();
  delay(1000);
}
#define NUMFLAKES     10 // Number of snowflakes in the animation example

#define LOGO_HEIGHT   16
#define LOGO_WIDTH    16
static const unsigned char PROGMEM logo_bmp[] =
{ B00000000, B11000000,
  B00000001, B11000000,
  B00000001, B11000000,
  B00000011, B11100000,
  B11110011, B11100000,
  B11111110, B11111000,
  B01111110, B11111111,
  B00110011, B10011111,
  B00011111, B11111100,
  B00001101, B01110000,
  B00011011, B10100000,
  B00111111, B11100000,
  B00111111, B11110000,
  B01111100, B11110000,
  B01110000, B01110000,
  B00000000, B00110000 };
void testdrawbitmap(void) {
  display.clearDisplay();

  display.drawBitmap(
    (display.width()  - LOGO_WIDTH ) / 2,
    (display.height() - LOGO_HEIGHT) / 2,
    logo_bmp, LOGO_WIDTH, LOGO_HEIGHT, 1);
  display.display();
  delay(1000);
}

    // Draw each snowflake:
    for(f=0; f< NUMFLAKES; f++) {
      display.drawBitmap(icons[f][XPOS], icons[f][YPOS], bitmap, w, h, SSD1306_WHITE);
    }

}
*/

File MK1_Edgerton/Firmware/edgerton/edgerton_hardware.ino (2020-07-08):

//Functions to interact with hardware

void flashRoutine(){  //Handles flashing routine (charge, delay, flash, display current, save to EEPROM)

//If battery voltage is low, don't even try flashing
  if (batteryVoltage() < MIN_BATTERY_VOLTAGE * 10)soundError(1);

//Otherwise, attempt to charge flash
  else if (chargeFlash()) {

//If delay is set, flash after delay.  Otherwise, flash immediately on trigger
    if (!flashDelay) runFlash();
    else forceFlash();

//Turn off capacitor charger
    HIGH_VOLT_OFF;

//If button is not pressed, record to EEPROM
    if (BUTTON_NOT_PRESSED) {
      recordPerformance();
      unsigned long _t;
      _t = millis() + 3000;
      while (millis() < _t && BUTTON_NOT_PRESSED){};
      float _c;
      _c = (nextVolt - highVolt) / 8;
      _c *= CAPACITANCE_UF;
      _c *= 2;
      byte x[4] = {1, 2, 4, 8};
      _c /= x[menuPosition];
      _c *= 100;
    
      nextVolt *= 10000;
      nextVolt /= highVolt;

//If button is not pressed, display current output
      display.forceLineState(2, 0, 0b01111111);
      display.forceLineState(3, 0b01110011, 0b00001100);
      display.printInt(nextVolt);
      _t = millis() + 1000;
      while (millis() < _t && BUTTON_NOT_PRESSED){};
      display.setSegments(TXT_nothing);
      display.clearLineState();
      _t = millis() + 250;
      while (millis() < _t && BUTTON_NOT_PRESSED){};
      nextVolt = _c;
      display.forceLineState(2, 0, 0b01111111);
      display.forceLineState(3, 0b01110111, 0b00001000);
      display.printInt(nextVolt);
      _t = millis() + 1000;
      while (millis() < _t && BUTTON_NOT_PRESSED){};
      display.setSegments(TXT_nothing);
      display.clearLineState();
      _t = millis() + 250;
      while (millis() < _t && BUTTON_NOT_PRESSED){};
      REFRESH_DISPLAY;

//Wait for trigger to reset and button to release
        while (!TRIGGER_HIGH || BUTTON_PRESSED){}; 
      }
  }
}

bool chargeFlash(){ //Handles capacitor charging, returns true if charged / false if not charged

//Display voltage
  display.clearLineState();
  display.printInt(analogRead(HIGH_VOLT_OUT_ANALOG) * capacitorVoltCal);
  highVolt = 0;

//Turn on high-voltage converter and begin charging capacitors
  HIGH_VOLT_ON;

//Audio notification
  soundCharging();

//Charge for 500 milliseconds and display capacitor voltage
  unsigned long _t = millis() + 500;
  while (millis() < _t) display.printInt(capacitorVoltage());

//Charge for up to 4 seconds and wait for voltage to normalize, display capacitor voltage
  byte i = 10;
  while (i && analogRead(HIGH_VOLT_OUT_ANALOG) > highVolt + 1){
    readBtn();
    i--;
    highVolt = analogRead(HIGH_VOLT_OUT_ANALOG);
    _t = millis() + 400;
    soundTick();
    while (millis() < _t || BUTTON_PRESSED) {
      display.printInt(capacitorVoltage());
      delay(50);
    }
  }

//Measure capacitor voltage
  highVolt = 0;
  for (byte i = 0; i < 8; i++) highVolt += analogRead(HIGH_VOLT_OUT_ANALOG);
  highVolt = highVolt >> 3;

//If capacitor voltage exceeds safety limit, stop charging and return false signal
  if (capacitorVoltage() > MAX_CAPACITOR_VOLTAGE){
    soundError();
    HIGH_VOLT_OFF;
    return false;
  }

//Audio notification capacitors are charged
  soundDone();

//Return charged signal
  return true;
}

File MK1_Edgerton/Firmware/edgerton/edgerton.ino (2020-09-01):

/*
  Firmware for Edgerton High-Speed LED flash
  Written by Tyler Gerritsen
  vtgerritsen@gmail.com
  www.td0g.ca

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
CHANGELOG
0.1 2019-04-27
  Functional
  
0.2 2019-05-05
  Added EEPROM Data Logging
  Displays Voltage Drop and Current after flash
  Many bug fixes

0.2.1 2019-05-10
  Bug fixes
  
0.2.2  2019-05-15
  Changed display library
  Improved trigger response time slightly
  Replaced relay with MOSFET

0.2.3  2019-06-08
  Sound!
  New tripwire function
  Added colon control to TM1637 code
  Removed high-voltage input sensor
  General code hygiene improvements

0.2.4  2019-06-28
  Trigger now automatically detects active low/high, will activate on signal change
  Chirp indicates trigger state change when not in standby mode
  Improved delay precision
  
0.2.5  2019-09-26
  Fixed issue where flash would only fire for 500 ns, regardless of menu option selection

0.2.6 2019-11-03
  New MAX VOLTAGE feature, unit will not flash if voltage exceeds value
  More intelligent capacitor voltage calibrating system (shows live output of capacitor voltage)
  
0.2.7	2019-11-19
	Bug Fixes

0.2.8 2020-03-27
  Documentation of all functions
  Battery voltage display bug fixed
  Removed unused variables

0.2.9 2020-07-09
  Disables interrupts prior to strobing
  Fixed bug in Performance Recording function
*/

//Basic Configuration
  #define MIN_BATTERY_VOLTAGE 8.5   //Capacitors will not charge if battery voltage is below this voltage
  #define MAX_CAPACITOR_VOLTAGE 125 //Flash will not trigger above this voltage
  #define BUTTON_DEBOUNCE 150   //Millis for button debounce
  #define BUTTON_LONGHOLD 700   //Millis for longhold
  #define CAPACITANCE_UF 3.3    //Microfarads Per LED
  #define EIGHT_MHZ             //Comment out for 16 MhZ
  #define SOUND                 //Comment out if no piezo buzzer is installed
  #define EEPROM_HISTORY_END 1012 //Leave two bytes for flash counter, eight for voltage calibration
  #define DISPLAY_TIMEOUT 6000    //Display will darken after this milliseconds

//Pulse Duration Calibration
  #define DELAY_500NS NOP; NOP;
  #define DELAY_1US NOP;NOP;NOP;NOP;NOP; 
  #define DELAY_2US DELAY_500_NS;DELAY_500_NS;NOP;NOP;//DELAY_500_NS;
  #define DELAY_4US DELAY_500_NS;DELAY_500_NS;DELAY_500_NS;DELAY_500_NS;DELAY_500_NS;DELAY_500_NS;

//Pin Configuration
  #define DISPLAY_CLK_PIN 3 //TM1637 Module
  #define DISPLAY_DIO_PIN 4 //TM1637 Module
  #define SOUND_PIN 11
  #define FLASH_PIN 8       //TC4452 Gate Driver Input (via High-Pass)
  #define FLASH_ON PORTB = 0b00000011
  #define FLASH_OFF PORTB = 0b00000010
  #define BUTTON_PIN 18
  #define BUTTON_PRESSED !(PINC & 0b00010000)
  #define BUTTON_NOT_PRESSED PINC & 0b00010000
  #define ENCODER_A_PIN 19
  #define ENCODER_B_PIN 2
  #define ENCODER_STATE ((PINC & 0b00100000) >> 5) | ((PIND & 0b00000100) >> 1)
  #define TRIGGER_PIN 17 //10
  #define TRIGGER_HIGH (PINC & 0b00001000)
  #define TRIGGER_HIGH_BUTTON_NOT_PRESSED (PINC & 0b00011000)
  #define TRIGGER_LOW (!(PINC & 0b00001000))
  #define TRIGGER_LOW_BUTTON_NOT_PRESSED (!(PINC & 0b00001000) && (PINC & 0b00010000))
  #define HIGH_VOLT_PIN 5
  #define HIGH_VOLT_ON digitalWrite(HIGH_VOLT_PIN, 1);
  #define HIGH_VOLT_OFF digitalWrite(HIGH_VOLT_PIN, 0);
  #define HIGH_VOLT_OUT_ANALOG 14
  #define INPUT_VOLT_ANALOG 16

//Other Definitions - DO NOT EDIT
  #define NOP __asm__ __volatile__ ("nop\n\t")
  #ifdef EIGHT_MHZ
    #define DELAY_500_NS NOP; NOP; NOP; NOP
  #else
    #define DELAY_500_NS NOP; NOP; NOP; NOP; NOP; NOP; NOP; NOP
  #endif
  #define REFRESH_DISPLAY menuPosition = menuPosition | 0b10000000
  

//Tone Frequencies
  #define TONE_A 3520 //Good Volume
  #define TONE_A_S 3729 //Good Volume
  #define TONE_B 3951 //Good Volume
  #define TONE_C 4186 //Good Volume
  #define TONE_C_S 4435
  #define TONE_D 4698
  #define TONE_D_S 4978
  #define TONE_E 5274
  #define TONE_F 5588
  #define TONE_G 6272

//Display
  #include "TD0G_1637.h"
  tm1637 display(DISPLAY_CLK_PIN, DISPLAY_DIO_PIN);
  const uint8_t TXT_all[] = {255, 0, 255, 0};
  const uint8_t TXT_nothing[4] = {0, 0, 0, 0};

//Non-Volatile Memory
  #include <EEPROM.h>

//Global Variables
  unsigned long flashDelay = 0;
  byte menuPosition = 0;
  byte flashDuration = 1;
  unsigned long highVolt;
  unsigned long nextVolt;
  unsigned long nextVolt2;
  unsigned int flashCount;
  float batteryVoltCal;
  float capacitorVoltCal;

void setup() {
//GPIO Setup
  pinMode(FLASH_PIN, OUTPUT);
  digitalWrite(FLASH_PIN, 0);
  HIGH_VOLT_OFF;
  pinMode(ENCODER_B_PIN, INPUT_PULLUP);
  pinMode(ENCODER_A_PIN, INPUT_PULLUP);
  pinMode(BUTTON_PIN, INPUT_PULLUP);
  pinMode(HIGH_VOLT_OUT_ANALOG, INPUT);
  pinMode(INPUT_VOLT_ANALOG, INPUT);
  pinMode(HIGH_VOLT_PIN, OUTPUT);
  pinMode(TRIGGER_PIN, INPUT_PULLUP);
  #ifdef SOUND
    pinMode(SOUND_PIN, OUTPUT); //3500 - 4100
  #endif

//Display
  display.setSegments(TXT_nothing);
  display.setBrightness(7);
  display.flipDisplay(1);
  REFRESH_DISPLAY;

//Serial
  Serial.begin(9600);
  Serial.println("EDGERTON Ready");

//Calibration
  EEPROM.get(EEPROM_HISTORY_END, batteryVoltCal);
  EEPROM.get(EEPROM_HISTORY_END + 4, capacitorVoltCal);
  initialSetup();
  
//Welcome Tone
  soundStartup();

//Get flash count
  flashCount = readFlashCount();

//Turn off display colon
  display.colon(0);
}

void loop() {runDisplay();runUI();runSerial();runAudio();}

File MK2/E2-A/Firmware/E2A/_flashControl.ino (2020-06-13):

//The only functions which can execute strobes!

void enterFullyArmedState(){
  //Wait for trigger to enter non-active state
    soundDone();
    delay(200); //Waiting for sound to finish
    while (!activeTrigger && TRIGGER_LOW){};
    while (activeTrigger && TRIGGER_HIGH){};

  //Notify user that strobe is armed
    display.clearDisplay();
    display.display();

  //Execute
    runFlash();

  //Notify user that trigger has occurred and wait for trigger to enter non-active state
    soundDone();
    menuPosition = 4 | 0b10000000;
    delay(800);
    while (!activeTrigger && TRIGGER_LOW){};
    while (activeTrigger && TRIGGER_HIGH){};
    printDisplayMain();
}

void runFlash(){
  byte _pinNoTrigger;
  _pinNoTrigger = PINC & 0b00001000;
  unsigned int _t = delayTime[pulseRate];
  if (!flashDelay){
    cli();
    switch (pulseDuration){
    case 0:
      while ((PINC & 0b00001000) == _pinNoTrigger){};
      TCNT1 = 0;
      FLASH_ON;
      DELAY_500_NS;
      FLASH_OFF;
      for (byte i = 1; i < pulseCount; i++){         
        while(TCNT1 > _t){};
        while (TCNT1 < _t){};
        FLASH_ON;
        DELAY_500_NS;
        FLASH_OFF;
        _t += delayTime[pulseRate];
      }
    break;
    case 1:
      while ((PINC & 0b00001000) == _pinNoTrigger){};
          TCNT1 = 0;
      FLASH_ON;
      DELAY_1US;
      FLASH_OFF;
      for (byte i = 1; i < pulseCount; i++){        
        while(TCNT1 > _t){};
        while (TCNT1 < _t){};
        FLASH_ON;
        DELAY_1US;
        FLASH_OFF;
        _t += delayTime[pulseRate];
      }
    break;
    case 2:
      while ((PINC & 0b00001000) == _pinNoTrigger){};
          TCNT1 = 0;
      FLASH_ON;
      DELAY_2US;
      FLASH_OFF;
      for (byte i = 1; i < pulseCount; i++){     
        while(TCNT1 > _t){};
        while (TCNT1 < _t){};
        FLASH_ON;
        DELAY_2US;
        FLASH_OFF;
        _t += delayTime[pulseRate];
      }
    break;
    case 3:
      while ((PINC & 0b00001000) == _pinNoTrigger){};
          TCNT1 = 0;
      FLASH_ON;
      DELAY_4US;
      FLASH_OFF;
      for (byte i = 1; i < pulseCount; i++){      
        while(TCNT1 > _t){};
        while (TCNT1 < _t){};
        FLASH_ON;
        DELAY_4US;
        FLASH_OFF;
        _t += delayTime[pulseRate];
      }
    break;
    default: break;
    }
  }

  else {
    unsigned long _halfMicros = flashDelay;
    _halfMicros *= 16000;
    _halfMicros = _halfMicros >> 16;
    unsigned int _ovf = _halfMicros;
    _halfMicros = flashDelay;
    _halfMicros *= 16000;
    unsigned int _count = _halfMicros;
    Serial.println(_count);
    Serial.println(_ovf);
    while ((PINC & 0b00001000) == _pinNoTrigger){};
    TCNT1 = 0;
    switch (pulseDuration){
    case 0:
    while (_ovf){
      while (TCNT1 < 32000){};
      while (TCNT1 > 30000){};
      _ovf--;
    }
    while (TCNT1 < _count){
      if (TCNT1 >= _ovf) _ovf = TCNT1;
      else _count = 0;
    }
      TCNT1 = 0;
      FLASH_ON;
      DELAY_500_NS;
      FLASH_OFF;
      for (byte i = 1; i < pulseCount; i++){         
        while(TCNT1 > _t){};
        while (TCNT1 < _t){};
        FLASH_ON;
        DELAY_500_NS;
        FLASH_OFF;
        _t += delayTime[pulseRate];
      }
    break;
    case 1:
    while (_ovf){
      while (TCNT1 < 32000){};
      while (TCNT1 > 30000){};
      _ovf--;
    }
    while (TCNT1 < _count){
      if (TCNT1 >= _ovf) _ovf = TCNT1;
      else _count = 0;
    }
          TCNT1 = 0;
      FLASH_ON;
      DELAY_1US;
      FLASH_OFF;
      for (byte i = 1; i < pulseCount; i++){        
        while(TCNT1 > _t){};
        while (TCNT1 < _t){};
        FLASH_ON;
        DELAY_1US;
        FLASH_OFF;
        _t += delayTime[pulseRate];
      }
    break;
    case 2:
    while (_ovf){
      while (TCNT1 < 32000){};
      while (TCNT1 > 30000){};
      _ovf--;
    }
    while (TCNT1 < _count){
      if (TCNT1 >= _ovf) _ovf = TCNT1;
      else _count = 0;
    }
          TCNT1 = 0;
      FLASH_ON;
      DELAY_2US;
      FLASH_OFF;
      for (byte i = 1; i < pulseCount; i++){     
        while(TCNT1 > _t){};
        while (TCNT1 < _t){};
        FLASH_ON;
        DELAY_2US;
        FLASH_OFF;
        _t += delayTime[pulseRate];
      }
    break;
    case 3:
    while (_ovf){
      while (TCNT1 < 32000){};
      while (TCNT1 > 30000){};
      _ovf--;
    }
    while (TCNT1 < _count){
      if (TCNT1 >= _ovf) _ovf = TCNT1;
      else _count = 0;
    }
          TCNT1 = 0;
      FLASH_ON;
      DELAY_4US;
      FLASH_OFF;
      for (byte i = 1; i < pulseCount; i++){      
        while(TCNT1 > _t){};
        while (TCNT1 < _t){};
        FLASH_ON;
        DELAY_4US;
        FLASH_OFF;
        _t += delayTime[pulseRate];
      }
    break;
    default: break;
    }
  }
  FLASH_OFF;
  sei();
  incrementFlashCount();
}

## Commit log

2019-10-05 Corrected high-voltage booster connections
2019-11-04 New firmware
    New MAX_CAPACITOR_VOLTAGE
    Improved calibration setup
2020-07-07 Organized into MK1 and MK2 folders
    [BOM 1.2c.csv]
2020-08-31 Update 2020-08-31
    [Back.stl, Battery Door.STL, Dial.STL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]
2020-08-31 Corrected mounting hole positions (86mm X spacing)

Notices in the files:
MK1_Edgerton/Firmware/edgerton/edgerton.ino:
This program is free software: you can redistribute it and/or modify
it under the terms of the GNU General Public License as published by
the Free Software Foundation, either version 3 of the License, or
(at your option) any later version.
